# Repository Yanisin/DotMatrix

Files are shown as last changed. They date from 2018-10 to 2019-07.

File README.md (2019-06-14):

# DotMatrix

## What is this?

A STM32F070CB driving a LED DotMatrix.

## Prerequisities for building Firmware

  * You need an appropriate Cortex-M ARM toolchain. We suggest to use the
  ARM's [GNU Embedded Toolchain for Arm ](https://developer.arm.com/tools-and-software/open-source-software/developer-tools/gnu-toolchain/gnu-rm/downloads).
  Please note that the `gcc-arm-none-eabi` provided by Ubuntu 18.04 is currently broken and can't be used.

  * This project makes use of [libopencm3]()https://github.com/libopencm3/libopencm3) and [ChibiOS](http://www.chibios.org).
  In order to build `libopencm3` you need `Python 2`.

  * To download the firmware, you have two options:
     - Via USB: You need `dfu-util 0.9+` and a USB cable. Please not that `dfu-util 0.8` will not work.
     - Via SWD: You need `openocd` and a `ST-LINK v2 device`
  
  * Optional: `Docker`

You might be interested in some [libopencm3 examples here](https://github.com/libopencm3/libopencm3-examples).

The pull requests there might be an interesting source of information as well.

You will also want to have the manuals for your hardware at hand. These are the most important for software development:
 - Peripherals, memory layout, registers ... : [STM32F030x4/x6/x8/xC and STM32F070x6/xB MCUs](https://www.st.com/resource/en/reference_manual/dm00091010.pdf)
 - Pinouts, Electric Characteristcs, HW variants, clocks ...:
   [STM32F070CB Product Specification](https://www.st.com/resource/en/datasheet/stm32f070cb.pdf)
 - Exceptions (NVIC), instructions ... :
   [ARM® v7-M Architecture Reference Manual](https://static.docs.arm.com/ddi0403/eb/DDI0403E_B_armv7m_arm.pdf)

## Install & Build

Get the code:

    $ git clone https://github.com/libopencm3/libopencm3.git
    $ git clone https://github.com/ChibiOS/ChibiOS.git
    $ git clone https://github.com/Yanisin/DotMatrix.git

We provide a Dockerfile, containing the suggested toolchain, openocd, dfu-util and other tools as well.
You can build the container with:

    $ cd DotMatrix/
    DotMatrix$ docker build -t gcc-arm-none-eabi-8-2018-q4 .

Create a file named `settings.mk` in `DotMatrix/src` and provide an appropriate configuration.
You can use `DotMatrix/src/settings.mk.example` as input. This `settings.mk` works with the Docker container:

```
OPENCM3_DIR ?= /home/dev/app/src/libopencm3
CHIBIOS ?= /home/dev/app/src/ChibiOS
HW_VERSION = "HW_60x60_rev_0_5"
SUDO=
SIM=0
OOCD ?= openocd
OOCD_INTERFACE ?= stlink-v2-1
OOCD_TARGET ?= stm32f0x
```

You can start the container with:

    DotMatrix$ docker run -it --privileged --expose 4444 \
                  -v /dev/bus/usb:/dev/bus/usb \
                  -v `pwd`/../libopencm3:/home/dev/app/src/libopencm3 \
                  -v `pwd`/../ChibiOS:/home/dev/app/src/ChibiOS \
                  -v `pwd`:/home/dev/app \
                  gcc-arm-none-eabi-8-2018-q4:latest /bin/bash

You need to compile `libopencm3` before usage. This has to be done once.
With help of the toolchain container this is:

    dev@59e291eed30d:~/app$ cd src/libopencm3/
    dev@59e291eed30d:~/app/src/libopencm3$ make

ChibiOS is compiled on demand.

To compile the firmware / demo of your interest, just go to the directory and issue `$ make`. For instance:

    dev@59e291eed30d:~/app$ cd src/full/
    dev@59e291eed30d:~/app/src/full$ make

This should result in a binary `build/full.elf`.

### Content of the package

The software demos live in the src directory. There are are three main demos
avaiable:

- `src/stm32f070_miniblink` - a simple demo just blinking the LED
- `src/GameOfLife` - GameOfLife with all connected cells working together.
  Simple communication protocol over UART. The demo uses just libopencm3
  for HW interfacing.
- `src/full` - the 'catch all' demo. Includes GameOfLife and other applications
  that are selectable with an 'applet selector'. Provides a communication
  layer over I2C and UART. Automatically detects the topology of the boards
  at startup and chooses a 'master board'. Is based on an RTOS (ChibiOS).

There are also other small testing projects and a simulator that allows you to
run the 'full' demo on your host machine.

## Flashing

Flashing is done using the `make prg` and `make prg_usb` commands.
See `src/common.mk` for other makefile commands.

### SWD Interface

Attach the SWD interface of the MCU via stlink-v2 programmer and issue `$ make prg`

### USB DFU Bootloaders

There are two USB bootloaders.  One is burnt int the MCU from the manufacturer.
This one can be used in case of emergency to write "more specialized" bootloader stored 
in the FLASH, and that is used the flash the actual firmware.

The MCU itself has a bootloader burnt from the manufacture. This one requires
the Y1 oscillator popullated in order to work. It can be

#### Project Distributed Bootloader

There is a bootloader in `src/dfu`. Among other nice features this bootloader
allows to flash multiple interconnected boards at the same time.
Once compiled it can be flashed to ieach of the MCUs either using the stlink-v2
programer ( using `make prg` commad) or via the MCUs built in bootloader (using
the "make prg_bl" command).

If you want to use this bootloader (recommneded way), issue `$ make prg_usb` in
your project and connect the board over USB (or restart it, if it is already
connected. The flashing process will start as soon as the board reaches the
bootlader (you will see threee dots). If multiple boards are connected and
started at once, the firmware will be loaded to all of them.

The USB part of this bootloader seems to work even without Y1 resonator
populated, but the manufacturer does not say that it should be relyable.
If you have the the Y1 not populated keep this in mind.

#### MCU Manufacturers Bootloader

The MCU has a built in bootloader that is started if the BOOT0 pin is held hight
after reset is released. On the board there is reset circuitry with button.
If you hold this `reset` button for several seconds, you will get the board into
manufacturer provided bootloader. Among other ways (like USART, SPI, I2C) this
bootloader can program the flash via the USB DFU protocol. Use `make prg_bl` to
talk to this bootloader.  This can be used to flash the project bootloader or
have the wonderfull feeling of running bare-metal. If you want to run your
project without the project bootloader, You have to compile the demo with
`NO_BOOTLOADER=1`. 

Keep in mind that you can use this bootloader in USB DFU mode only if there is
the Y1 resonator present. If the Y1 is not present, you will need to use the
stlink-v2 or some other interface that this bootloader can handle even without
oscillator.  For details about this bootloader search for STs AN2606.

## Memory layout

Even though that you are programming C, it is important to know the memory
layout for debugging etc. The makefiles will take care of linking the code
at correct addreses.

ROM is mapped at 0x08000000 and the layout is as follows:

 Address | Size     | Usage
---------|----------|------------------------------------
0x0      | 0x4000   | Project Distributed Bootloader
0x4000   | 0x1C000  | Your application code (interrupt vectors, .text, .data)

RAM is mapped at 0x20000000 and the layout is as follows.

 Address | Size     | Usage
---------|----------|--------------------------------------------------------
0x0      | 0x100    | Interrupt vectors (loaded from ROM)
0x100    | 0x3F00   | Your application data (.data loaded from ROM, .bss)

For the location of IO registers for peripherals, consult the ST manual

# Hardware and mechanical parts
The currently used/latest HW is described in "pcb/60x60_dma". The board
is designed with KiCAD but there is the schematics exported in PDF 
and some assembly hints with list of needed parts are added as well.
The other folders in "src" are mostly unfinished various experiments/extension.

In the "mechanical" folder you can find the mechanical parts for 3D printing.
For each board PCB you will need one disp_support.stl.  The file is expected to
be printed with 0.4mm nozzle and 0.15mm layer height.  For connecting boards
you can use joint_cross_1_5m.stl for each corner (in older revision of the
board there is LED in the way so you need the use the one with the cuts for the
LED).

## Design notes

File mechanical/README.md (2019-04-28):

# Mechanical parts

The stl files are "fine tuned" for Creality Ender 3 with 0.4mm nozzle.
If some "tuning" is needed because of different printer they gen be recreated
using OpenSCAD.

## For Standalone Module

You need:
 
- 1x printed disp_support.stl
- 4x M3 nut
- 4x M3 15mm long spacer, one end male one end female (preferably nylon)

## For connecting modules
for each corner you will need joint_cross_1.5mm.stl.

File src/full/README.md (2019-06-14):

# DotMatrix full demo

This demo is a full-featured demo providing a common base for your hacking needs. It is based around
an RTOS (ChibiOS) and lets the user choose between multiple applications. It provides some
convinience utilities, such as physical topology detection and messaging protocol. If you do
not need these aminities, you may want to look at the simpler GameOfLife demo.

To see how you can create an applet, take a look at `applets/hello.c`. Do not forget to add
your applet to the Makefile. You do not have to register it explicitely, it will be done
by the `applet_add` macro. The applet's `run` function will be run when the applet is selected.
It is recommanded to contain a `while (!applet_should_end)` loop. You might want to set
your applet as `autostart` during debugging.

## ChibiOS basics

You can find documentation for ChibiOS at http://chibios.sourceforge.net/docs/19.1/full_rm/index.html.

## Functions suffixes

`I` suffix signifies function can be called from ISR locked state.
`S` suffix signifies function can be called from locked state.
`X` suffix signifies function can be called from any.

### Quick reference

- Getting current time: `chVTGetSystemTimeX`
- Sleep: `chThdSleep`
- Specifying time-outs: use `TIME_MS2I`, `TIME_S2I` or `TIME_INFINITE`
- Non-blocking calls: pass `TIME_IMMEDIATE` as a time-out paremeter
- Wait for multiple events: use `chEvtRegister` -- see `chooser_run` in `chooser_applet.c`
- Absolute time-outs: see `util/timeout.h`
- Panic: `chSysHalt`
- Memory allocation: `<chmemheaps.h>` `chHeapAlloc`
- Create a task: use `chThdCreateStatic` with working area allocatd by `THD_WORKING_AREA`

### Debugging

OpenOCD has support for ChibiOS threads. Use `info threads` and `thread X` to show and switch
threads respectivelly.

Also check `util/stack_usage.c` which you can use to get the biggest stack usage so far. Paste
these lines into GDB:
```
p stat_threads()
set print pretty on
p stat_thrinfo
```

## Messaging

There is a simple framing protocol which adds message IDs, checksum and routing information to
the messages. To send those messages, use either `i2c_send`, `i2c_broadcast` or `usart_send`.

To receive messages, the concept of message queues are used (`util/message_queue.h`). To get a
next message from the queue use `msg_rx_queue_get` and `msg_rx_queue_ack`. You will get a message
header and a "handle" to read the actual data from the queue buffer.

By default, the messages are automatically placed in the `default_queue` (both from i2c and uart).
If you want to change the queue, you can use the `dispatch_msg` callback of your applet.
This is used for example in the `GameOfLife`, where the time synchronization message (the tick)
is placed in a different queue than other messages.

## Hardware

Apart from UART and I2C (see previous paragraph), there are APIs for:
 - Buttons: `hw/buttons.h`
 - USB serial console: `console.h`
 - Unique Cell ID: `cell_id.h` (most of the time, you will want to use the short id from topology)
 - LED Matrix display: `hw/disp.h`

## Topology

When the full demo starts, it automatically enumerates all connected boards and elects a master
board. You can use this topology information to do proper display rotation (all boards can
show images rotated the same way), address the boards
over I2C or decide what will be shown on what board. Check the `util/topo.h` for more information.

## Other utilities

We have already touched on the topic of message queues. There is an alternative for streams without
any framing (`util/byte_queue.h`).

There are also utilities for basic operations with 2d integer vectors (used mostly for cell positions).

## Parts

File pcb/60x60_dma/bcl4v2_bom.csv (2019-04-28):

Reference | Quantity | Value | price [Kc] | price total | farnell | case | Datasheet
C1 C10 C3 | 3 | 4u7 | 2,6 | 7,8 | https://cz.farnell.com/taiyo-yuden/emk212b7475kg-t/cap-4-7-f-16v-10-x7r-0805/dp/2112841 | SMD 0805
C12 C13 | 2 | 220u | 16 | 32 | https://cz.farnell.com/avx/tajd107k010rnj/cap-100-f-10v-10-2917-reel/dp/2217319 | EIA-7343-20
C14 C15 | 2 | 2pF | 0,67 | 1,34 | https://cz.farnell.com/multicomp/mc0603n2r0c500ct/cap-2pf-50v-c0g-np0-0603/dp/1759043RL | SMD 0805
C11 C2 C4 | 3 | 100n | 0,6 | 1,8 | https://cz.farnell.com/multicomp/mcu0805r104kct/cap-0-1-f-50v-10-x7r-0805/dp/9406387 | SMD 0805
C6 C7 C8 C9 | 4 | 100n | 0,6 | 2,4 | https://cz.farnell.com/multicomp/mc0603b104m250ct/cap-0-1-f-25v-20-x7r-0603/dp/2627428 | SMD 0805
D1 D2 | 2 | Shottky | 1,48 | 2,96 | https://cz.farnell.com/taiwan-semiconductor/b0520lw-rhg/diode-rectif-20v-0-5a-sod123/dp/1863141 | SOD-123
D5 | 1 | LED | 0,3 | 0,3 | ebay | SMD 0805
D6 | 1 | LED_MATRIX_8x8 | 70 | 70 | https://www.ges.cz/cz/spl-32-GES06600358.html | LED_MATRIX_8x8_60.2mmx60.2mm
J1 J2 J4 J5 J6 J7 J8 J9 | 8 | Conn_01x05 | 0,7375 | 5,9 | https://www.ges.cz/cz/pls-40s-GES06600276.html | Pin_Hdr_1x05_2.54mm
 |  |  |  | 0
J14 | 1 | Conn_01x02 | 0,3 | 0,3 | https://www.ges.cz/cz/pls-40r1-GES06614710.html | Pin_Hdr_1x02_2.54mm_angled_handsolder
J15 | 1 | Conn_01x04 | 0,6 | 0,6 | https://www.ges.cz/cz/pls-40r1-GES06614710.html | Pin_Hdr_1x04_2.54mm_angled_handsolder
J3 | 1 | USB_OTG | 6 | 6 | https://cz.farnell.com/multicomp/mc001009/micro-usb-type-b-receptacle-smt/dp/2506104?st=micro%20usb | USB_Micro-B
Q1 | 1 | BSS138 | 1,71 | 1,71 | https://cz.farnell.com/nexperia/bss138p-215/mosfet-n-ch-60v-0-36a-sot23/dp/1859849?st=bss138 | SOT-23
Q2 | 1 | IRLML6402 | 3,7 | 3,7 | https://cz.farnell.com/infineon/irlml6402trpbf/mosfet-p-ch-20v-3-7a-sot-23/dp/9103503?st=IRLML6402 | SOT-23
R14 R2 | 2 | 220k |  | 0 |  | SMD 0805
R15 R17 | 2 | R |  | 0 |  | SMD 0805
R16 | 1 | 820k |  | 0 |  | SMD 0805
R3 | 1 | 470 |  | 0 |  | SMD 0805
R1 R13 R4 | 3 | 10k |  | 0 |  | SMD 0805
R5 | 1 | 1k |  | 0 |  | SMD 0805
SW1 SW2 SW3 | 3 | SW_Push | 1,6666666667 | 5,0000000001 | lcsc | switch_K2-1112SA-A4SW-01
 |  |  |  | 0
U1 | 1 | MIC2091-1YM5-TR | 3,4 | 3,4 | https://cz.farnell.com/microchip/mic2091-1ym5-tr/power-switch-100ma-sot23-5/dp/2509914RL?st=mic2091 | SOT-23
U2 | 1 | STM32F070CBTx | 40 | 40 | provided by badger | LQFP-48_7x7mm_Pitch0.5mm
U3 | 1 | 74HC595 | 3,7 | 3,7 | https://cz.farnell.com/on-semiconductor/mc74hc595adtr2g/ic-sm-logic-74hc-register/dp/1607848?st=74HC595 | SO-16-N | http://www.ti.com/lit/ds/symlink/sn74hc595.pdf
U4 | 1 | TBD62783A(replaced by TD62783AFG) | 12 | 12 | https://www.ebay.com/itm/10pcs-NEW-TD62783AFG-SOP-18-TOSHIBA/282239141886 | SOIC-18W_7.5x11.6mm_Pitch1.27mm | http://toshiba.semicon-storage.com/info/docget.jsp?did=30523&prodName=TBD62783APG
U5 | 1 | TLC5916 | 24 | 24 | https://cz.farnell.com/texas-instruments/tlc5916id/ic-led-driver-linear-16-soic/dp/1755247?st=TLC5916 | SO-16-N
Y1 | 1 | Resonator | 10 | 10 |  | CSTCE_G
Y2 | 1 | ABS07-120-32.768kHz-T | 10 | 10 |  | crystal_ABS07-120-xx | ~
other:
 | 4 | nylon spacers
 | 4 | nylon nuts
 | 4 | mini breadboard joints

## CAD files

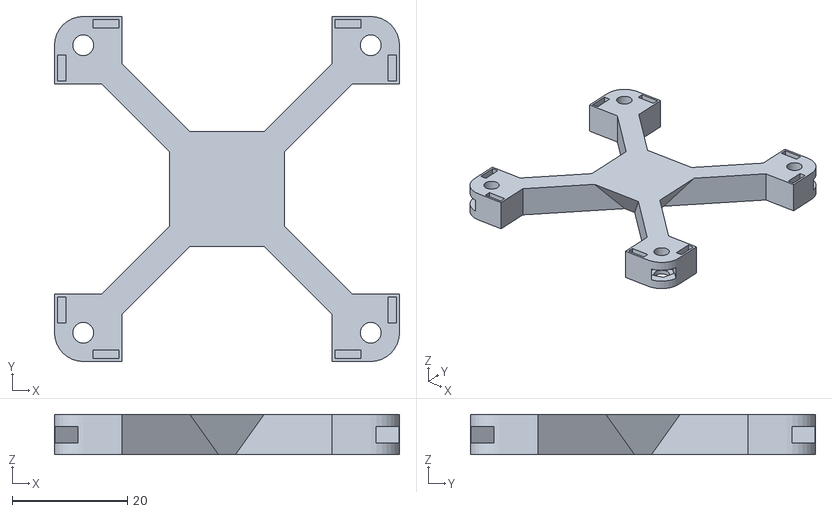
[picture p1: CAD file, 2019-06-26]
mechanical/disp_support_w_magnet.stl
60.0 x 60.0 x 7.00

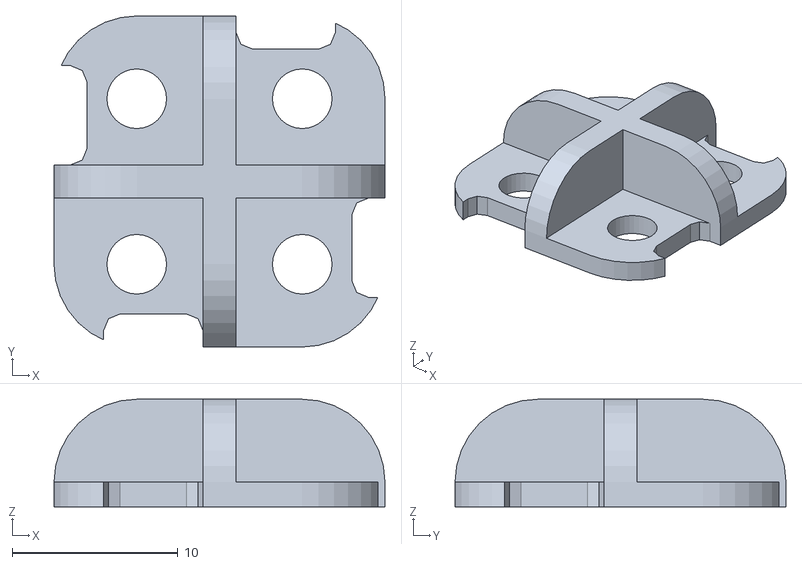
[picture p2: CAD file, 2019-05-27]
mechanical/joint_cross_1_5m_cut_for_v05.stl
20.0 x 20.0 x 6.50

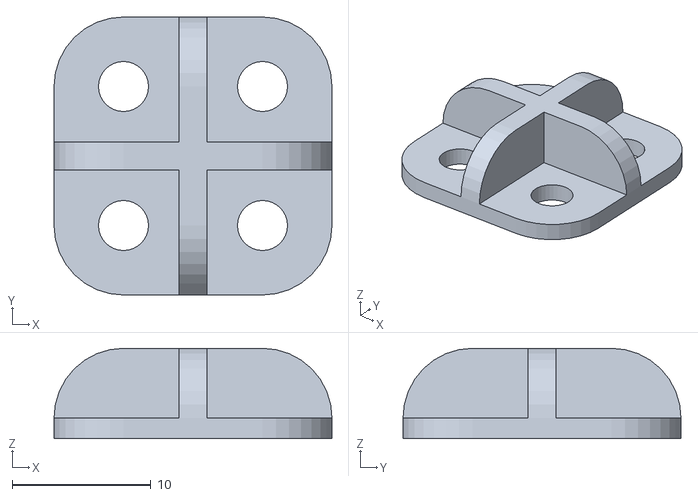
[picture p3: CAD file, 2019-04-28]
mechanical/joint_cross_1_5m.stl
20.0 x 20.0 x 6.50

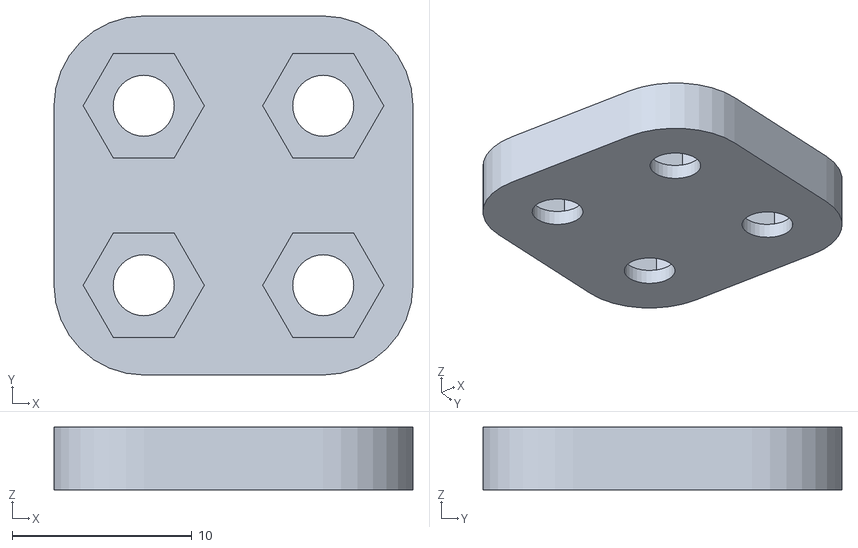
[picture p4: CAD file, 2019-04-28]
mechanical/joint_2x2_10mm.stl
20.0 x 20.0 x 3.50

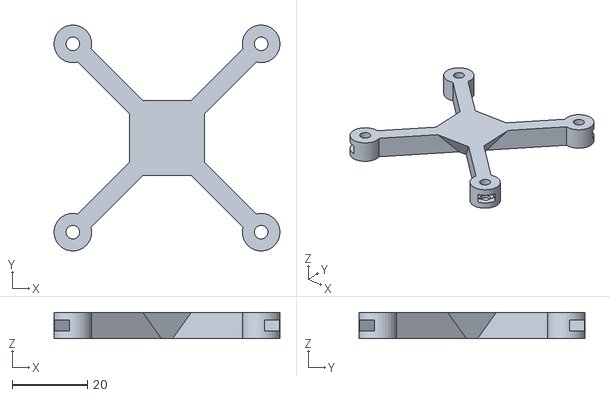
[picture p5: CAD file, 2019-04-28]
mechanical/disp_support.stl
60.0 x 60.0 x 7.00

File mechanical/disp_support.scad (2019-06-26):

hole_dia = 3.6;
corner_dia = 10;
corner_height = 7;
nut_height = 2.9;
nut_dia=0.8 + (5.5+6)/2;
nut_dia_clearance=0.4;
nut_offset = 1;
nut_recess = 1;
center_side=20;
center_height=7;
conn_width=2.54;
conn_length=2.54 * 14;
	corner_clearance=0.5;

//corner();

//body();
support();
$fn=32;
/* connector */
//color("red")
//translate([30 - conn_width,-conn_length/2,0])
//cube ([conn_width,conn_length, corner_height]);
 
module corner()
{
	
	union(){
	cylinder(h=corner_height,d=corner_dia);
	translate([0,-corner_dia/2,0])
	cube([25-conn_length/2-corner_clearance,corner_dia,corner_height]);
	rotate([0,0,-90])
	translate([0,-corner_dia/2,0])
	cube([25-conn_length/2-corner_clearance,corner_dia,corner_height]);
	}

}

module support()
{
difference(){
	body();
	holes();
	nut_holes();
	magnet_holes();
}
}

module hole(){
	cylinder(h=corner_height,d=hole_dia);
}

module nut_hole(){
	cube_width= nut_dia * sqrt(3)/2; 
	translate([0,0,nut_offset])
	cylinder(h=nut_height,d=nut_dia, $fn=6);
	translate([0,0,nut_offset+nut_recess]){
	cylinder(h=nut_height,d=nut_dia, $fn=6);
	translate([0,-cube_width/2,0])
	cube([20,cube_width,nut_height]);
}

}

module magnet_holes()
{
	magnet_x=1.5;
	magnet_y=4.5;
	magnet_z=6;
	x_offset=30 - magnet_x-0.5;
	/*0.5 is wall size around magnet*/
	y_offset = conn_length/2 + corner_clearance+0.5;
	z_offset = corner_height - magnet_z;

	translate([x_offset,y_offset,z_offset])
		cube([1.5,4.5,magnet_z]);
	translate([x_offset,-y_offset-magnet_y,z_offset])
		cube([1.5,4.5,magnet_z]);
	translate([-x_offset-magnet_x,y_offset,z_offset])
		cube([1.5,4.5,magnet_z]);
	translate([-x_offset-magnet_x,-y_offset-magnet_y,z_offset])
		cube([1.5,4.5,magnet_z]);
rotate([0,0,90]){
	translate([x_offset,y_offset,z_offset])
		cube([1.5,4.5,magnet_z]);
	translate([x_offset,-y_offset-magnet_y,z_offset])
		cube([1.5,4.5,magnet_z]);
	translate([-x_offset-magnet_x,y_offset,z_offset])
		cube([1.5,4.5,magnet_z]);
	translate([-x_offset-magnet_x,-y_offset-magnet_y,z_offset])
		cube([1.5,4.5,magnet_z]);}
}

module holes()
{
translate([25,25,0])
hole();
translate([25,-25,0])
hole();
translate([-25,25,0])
hole();
translate([-25,-25,0])
hole();
}

module nut_holes()
{
translate([25,25,0])
	rotate([0,0,45])
nut_hole();
translate([25,-25,0])
	rotate([0,0,-45])
nut_hole();
translate([-25,25,0])
	rotate([0,0,135])
nut_hole();
translate([-25,-25,0])
	rotate([0,0,-135])
nut_hole();
}


module body()
{
//translate([-center_side/2,-center_side/2,0])
//cube([center_side,center_side,center_height]);

translate([0,0,center_height/2])
linear_extrude(height = center_height, center = true, convexity = 10, slices =
20, scale = 2, $fn = 16) {
square([center_side*0.5,center_side *0.5],center=true);
}

rotate([0,0,45])
translate([-sqrt(2)*25,-2.5,0])
cube([2*sqrt(2)*25,5,corner_height]);
rotate([0,0,-45])
translate([-sqrt(2)*25,-2.5,0])
cube([2*sqrt(2)*25,5,corner_height]);
translate([25,25,0])
rotate([0,0,-90])
corner();
translate([25,-25,0])
rotate([0,0,180])
corner();
translate([-25,25,0])
rotate([0,0,0])
corner();
translate([-25,-25,0])
rotate([0,0,90])
corner();
}

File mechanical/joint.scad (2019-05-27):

use <metric_iso_screw.scad>


thickness = 1.5;
hole_dia = 3.6;
spacing = 10;
width = 10;
cross_thickness=2;
cross_height = 10;

rows=2;
//rows=2;

multiple_x = 4;
multiple_y = 4;
multiple_spacing=3;

nut_height=2.5;
nut_dia = 1 + (5.5+6)/2;


module body()
{
$fn=32;
	union(){
		translate([0,0,0])cylinder(h=thickness,d=width);
		translate([spacing,0,0])cylinder(h=thickness,d=width);
		translate([0,spacing*(rows-1),0])cylinder(h=thickness,d=width);
		translate([spacing,spacing*(rows-1),0])cylinder(h=thickness,d=width);
		translate([0,-width/2,0])cube([spacing,width+spacing*(rows-1),thickness]);
		translate([-width/2,0,0])cube([spacing+width,spacing*(rows-1),thickness]);
		/* cross */
		translate([0,spacing/2 - cross_thickness/2,thickness]) difference(){
			union(){
				rotate([-90,0,0])translate([0,0,0])cylinder(h=cross_thickness,d=width);
				rotate([-90,0,0])translate([spacing,0,0])cylinder(h=cross_thickness,d=width);
				translate([0,0,-spacing/2])cube([spacing,cross_thickness,spacing]);
			}
			translate([-spacing/2,0,-spacing])cube([spacing*2,spacing*(rows-1),spacing]);
		}

		translate([spacing/2 + cross_thickness/2,0,thickness]) rotate([0,0,90]) difference(){
			union(){
				rotate([-90,0,0])translate([0,0,0])cylinder(h=cross_thickness,d=width);
				rotate([-90,0,0])translate([spacing,0,0])cylinder(h=cross_thickness,d=width);
				translate([0,0,-spacing/2])cube([spacing,cross_thickness,spacing]);
				}
			translate([-spacing/2,0,-spacing])cube([spacing*2,spacing*(rows-1),spacing]);
		}

	}
}

module holes()
{
$fn=32;
	for (i = [0:(rows-1)]) {
		translate([0, i * spacing,0])cylinder(h=thickness,d=hole_dia);
		translate([spacing,i *spacing,0])cylinder(h=thickness,d=hole_dia);
	}
}


module holes_thread()
{
$fn=32;
	for (i = [0:(rows-1)]) {
		translate([0, i * spacing,0])
screw_thread_iso_inner(
        d=3,
        lt=6,
        $fn=60
    );



		translate([spacing,i *spacing,0])
screw_thread_iso_inner(
        d=3,
        lt=6,
        $fn=60
    );


	}
}


module nuts()
{
$fn=6;
	for (i = [0:(rows-1)]) {
		translate([0, i * spacing,0])cylinder(h=nut_height,d=nut_dia,$fn=6);
		translate([spacing,i *spacing,0])cylinder(h=nut_height,d=nut_dia,$fn=6);
	}
}

module joint() 
{
	difference () {
		body();
		holes();
		translate([0,0,thickness-nut_height])nuts();

	}
}


module joint_thread() 
{
	difference () {
		body();
		
		holes_thread();
//		translate([0,0,thickness-nut_height])nuts();

	}

}

module multiple()
{
		size_x = width + spacing;
		size_y = width + spacing * (rows -1);
	for (x = [1:multiple_x]) {
		for (y = [1:multiple_y]) {
		translate([(x-1)*(size_x+multiple_spacing),(y-1)*(size_y+multiple_spacing),0])joint();
		}
	}
}

module joint_simple()
{
	difference () {
		body();
		
		holes();
//		translate([0,0,thickness-nut_height])nuts();

	}

}

module joint_cut_v05()
{
difference(){
translate([-5,-5,0])
joint_simple();

translate([-6,-14,0])
minkowski(){
cylinder(r=1,h=2,$fn=8);
cube([4,5,5]);
}

rotate([0,0,90])
translate([-6,-14,0])
minkowski(){
cylinder(r=1,h=2,$fn=8);
cube([4,5,5]);
}


rotate([0,0,180])
translate([-6,-14,0])
minkowski(){
cylinder(r=1,h=2,$fn=8);
cube([4,5,5]);
}


rotate([0,0,270])
translate([-6,-14,0])
minkowski(){
cylinder(r=1,h=2,$fn=8);
cube([4,5,5]);
}

}
}

//multiple();
//joint_thread();
//joint_simple();

joint_cut_v05();

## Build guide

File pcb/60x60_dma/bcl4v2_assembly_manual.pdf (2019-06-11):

## Dot Matrix Assembly Manual

For hardware revision 0.6
Power Supply
Populate C1, C3, U1 and Q2. Verify that 5V test point is not shorted to GND neither to 3V3 test points. If not, you can apply 5V voltage on the GND and VCC pins of the J9 connector (see the other side of the PCB) and verify voltage on 5V and 3V3 test points.
Reset and Boot Selection
At least C11, R13 and R16 needs to be soldered to reliable boot the MCU. Bootloader can be then started by shorting the J14, applying power and disconnecting the short. If SW3, C10 and Q1 is populated, then SW3 can be used either to reset MCU (short press) or entering bootloader (long press). For now do not solder the SW3 yet as it will be in the way while soldering other parts.
Debug LED
Populate R5 and D5, while there solder R3 too. Keep in mind LED polarity (the green dots on the LED should align with the marked pin). Take care to not touch the LED resin blob with the soldering iron or not overheat the diode.
If the MCU (U2) is not soldered you can test LED by connecting TP6 to GND with power applied. If the MCU is already soldered, and the power is applied it should flash the LED several times.

## MCU and USB connector

You should be now skilled enough to solder the USB connector. Use 5V, GND, D+ and D- testpoints to check for shorts Then connect USB cable and check conductivity. If not presoldered now you can solder the MCU (U2) and the 0603 size capacitors C6, C7, C8, C9. If the preprogrammed MCU was used the LED should blink if you connect the power via the USB.

## External Clock

There are two types of external clock the High Speed one, used e.g. for USB and the Low Speed Clock that is used for RTC. For HSE (High Speed Clock) Y1 is needed. LSE (Low Speed Clock), Y2, C14, C15 are needed. LSE is not needed for this workshop, but it's easier to solder now, than on the complete kit.

## Led Matrix Driving

Solder U3,U4,U5 (R3 should be already in place). Use the LED matrix as the holder for soldering the "socket headers". Don't forget that the LED matrix should be on the other side of the PCB than the rest of the components. Once assembled correctly and powered the preloaded MCU should show some demo on the matrix.

## Buttons

This is optional. It makes the board more versatile and the demo can't be controlled without them. It's easier to do before the side headers are soldered but it still can be done later if you are getting short on time now. Solder SW1 and SW2 and R2, R14, C2, C4. (It's good time for SW3 now too.) The resistors and capacitors form the hardware button debounce. If you for some reason need a quick response on cost of doing the button debounce in software they can be omitted (the buttons can't be used in the demo in that case).

## Interface headers

The headers J1, J2, J4, J5, J6, J7, J8, J9 needs to be soldered now. The headers need to be as perpendicular to the PCB. If possible use a jig, or pile of another PCBs to hold the headers in place.

## Mechanical part

Now you should have the electrical part complete and you only need to complete the mechanical part. Insert the M3 nuts in the holes of the display support. You might eventually need do clean the 3D part a bit. The larger central part of the support should face upwards to the Display. If mounted remove the Display, and use the four nylon spacers to secure the display support on the PCB. Pay attention to properly aligned nuts in order to not damage the threading on the spacers. Reinstall the LED Display. The small 3D printed squares and small solder-less breadboards are for interconnecting the boards. The holes in the breadboard are connected in lines as the protrusion on top shows. If connected in wrong direction it will short circuit the header. The nuts with washers are for mounting the board to some support.

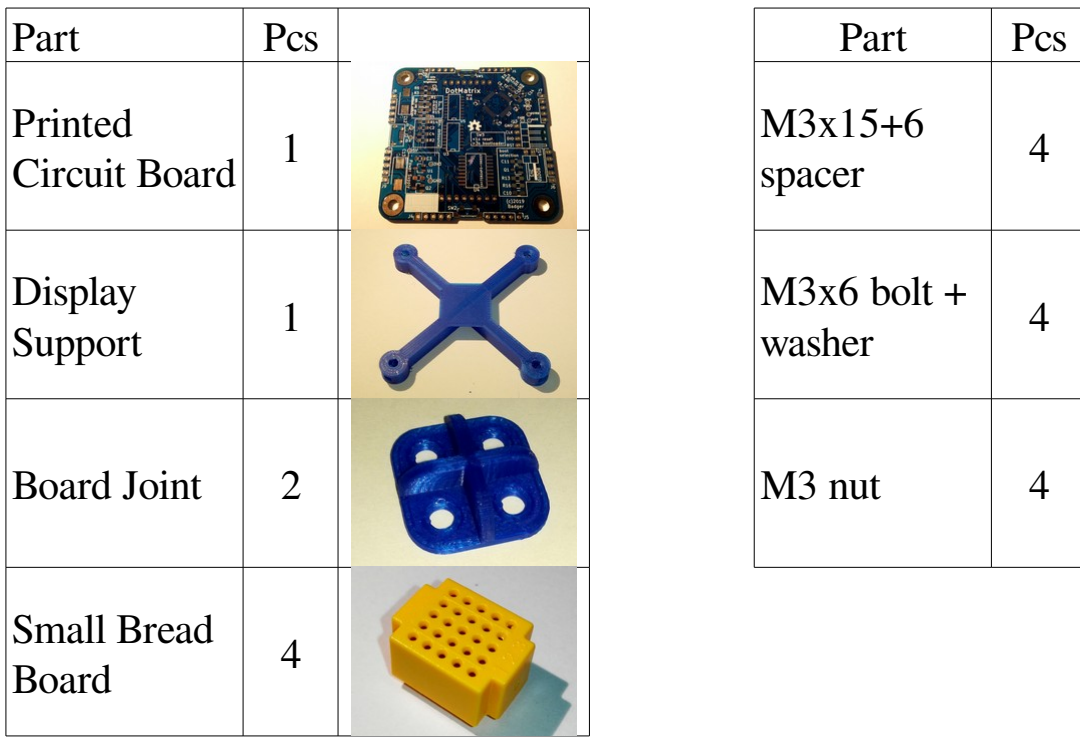
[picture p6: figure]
Part; Pcs; Printed; Circuit Board; M3x15+6 spacer; Display; Support; M3x6 bolt +; washer; Board Joint; M3 nut; Small Bread; Board

Table 1: Mechanical components

Reference | Pcs | Value | case
C1, C10, C3 | 3 | 4u7 | SMD 0805

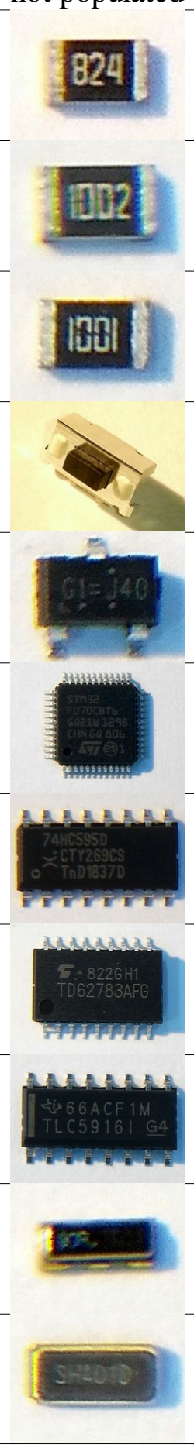
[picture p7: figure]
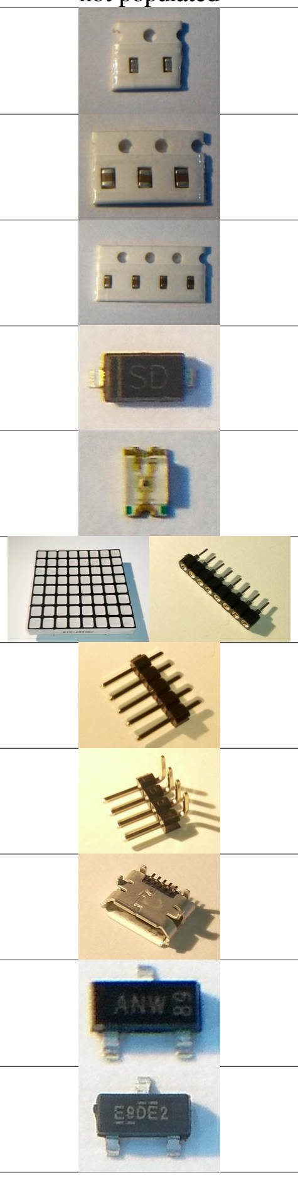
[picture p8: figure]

C12, C13 | 2 | 220u | EIA-7343-20 | not populated
C14, C15 | 2 | 2pF | SMD 0805
C11, C2, C4 | 3 | 100n | SMD 0805
C6, C7, C8, C9 | 4 | 100n | SMD 0805
D1, D2 | 2 | Shottky | SOD-123
D5 | 1 | LED | SMD 0805
D6 | 1 | | LED_8x8_60x6 0
J1, J2, J4, J5, J6, J7, J8, J9 | 8 | | Hdr_1x05_2.54
J15 | 1 | | hdr_1x04_2.54 angled
J3 | 1 | | USB_Micro-B
Q1 | 1 | BSS138 | SOT-23
Q2 | 1 | IRLML6402 | SOT-23
R14, R2 | 2 220k | SMD 0805
R15, R17 | 2 | R | SMD 0805 not populated
R16 | 1 | 820k | SMD 0805
R1, R13, R4 | 3 | 10k | SMD 0805
R3, R5 | 2 | 1k | SMD 0805
SW1, SW2, SW3 | 3 | | switch K2-1112SA
U1 | 1 | RT9166-33GVL | SOT-23
U2 | 1 | STM32F070C BTx | LQFP-48
U3 | 1 | 74HC595 | SO-16-N
U4 | 1 | TD62783AFG SOIC-18W
U5 | 1 | TLC5916 | SO-16-N
Y1 | 1 | Resonator | CSTCE_G
Y2 | 1 | ABS07-120-32.768kHz-T | ABS07-120-xx

Table 2: Components list

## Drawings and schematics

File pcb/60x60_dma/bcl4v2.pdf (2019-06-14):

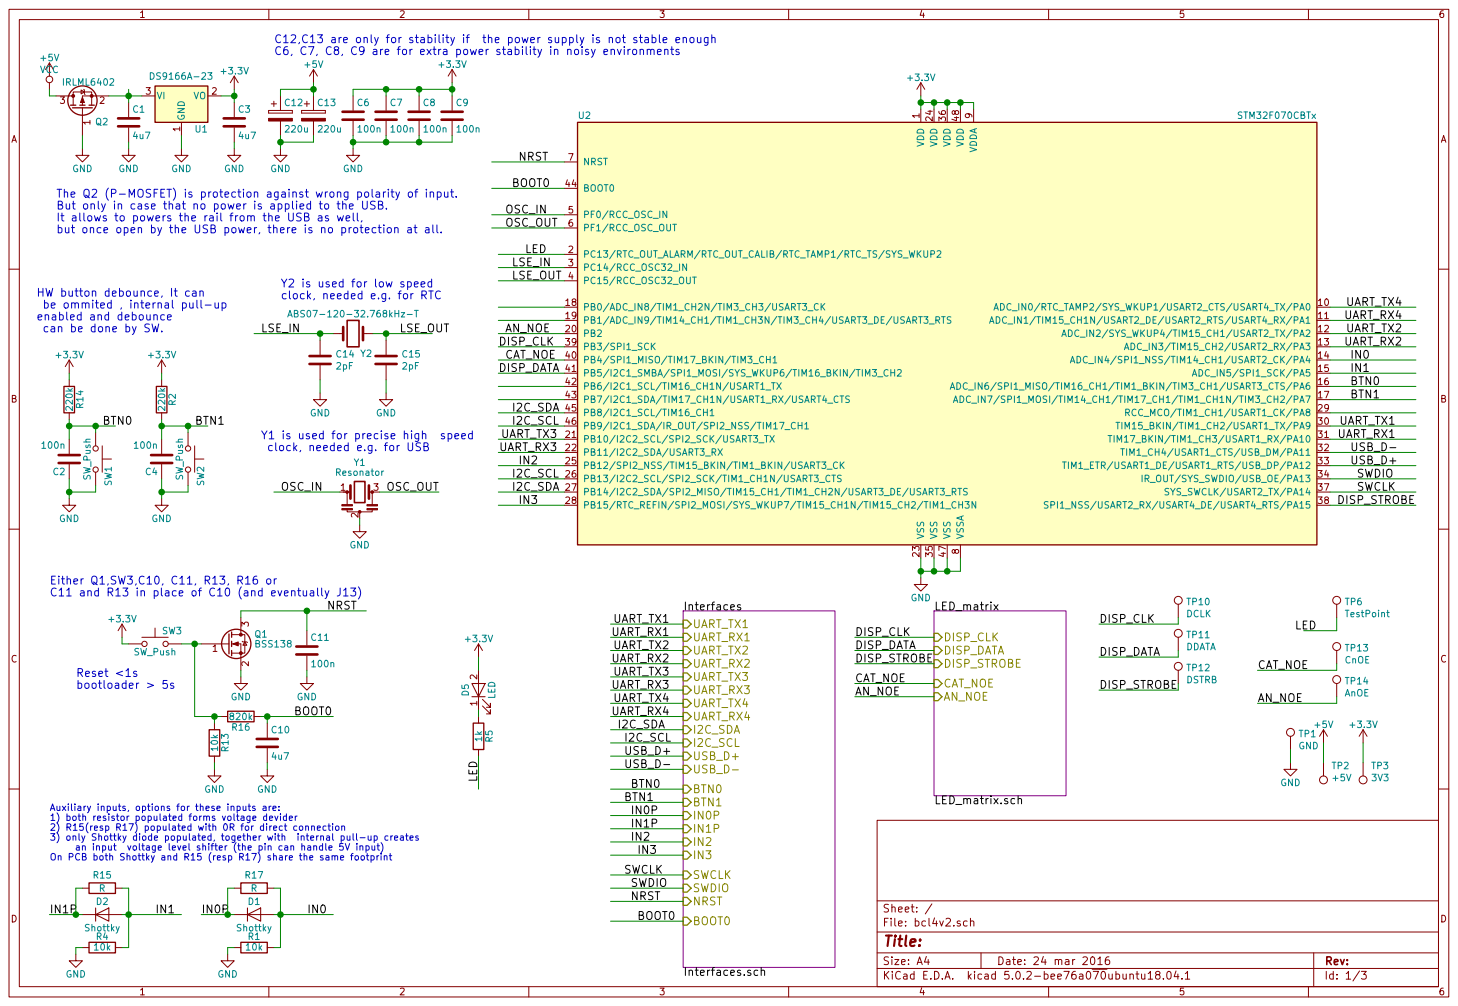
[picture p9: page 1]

can be done by SW. VCC
IRLML6402 GND The Q2 (P-MOSFET) is protection against wrong polarity of input.

C6, C7, C8, C9 are for extra power stability in noisy environments

But only in case that no power is applied to the USB.
It allows to powers the rail from the USB as well,
but once open by the USB power, there is no protection at all.

TP6 TestPoint Y2 is used for low speed
clock, needed e.g. for RTC
Y2 ABS07-120-32.768kHz-T C14

HW button debounce, It can
be ommited , internal pull-up
enabled and debounce

Y1 is used for precise high speed
clock, needed e.g. for USB

BOOT0 Reset <1s bootloader > 5s Either Q1,SW3,C10, C11, R13, R16 or
C11 and R13 in place of C10 (and eventually J13)

10k Auxiliary inputs, options for these inputs are:
1) both resistor populated forms voltage devider
2) R15(resp R17) populated with 0R for direct connection
3) only Shottky diode populated, together with internal pull-up creates
an input voltage level shifter (the pin can handle 5V input)
On PCB both Shottky and R15 (resp R17) share the same footprint

Id: 1/3 Title: File: bcl4v2.sch Sheet: /

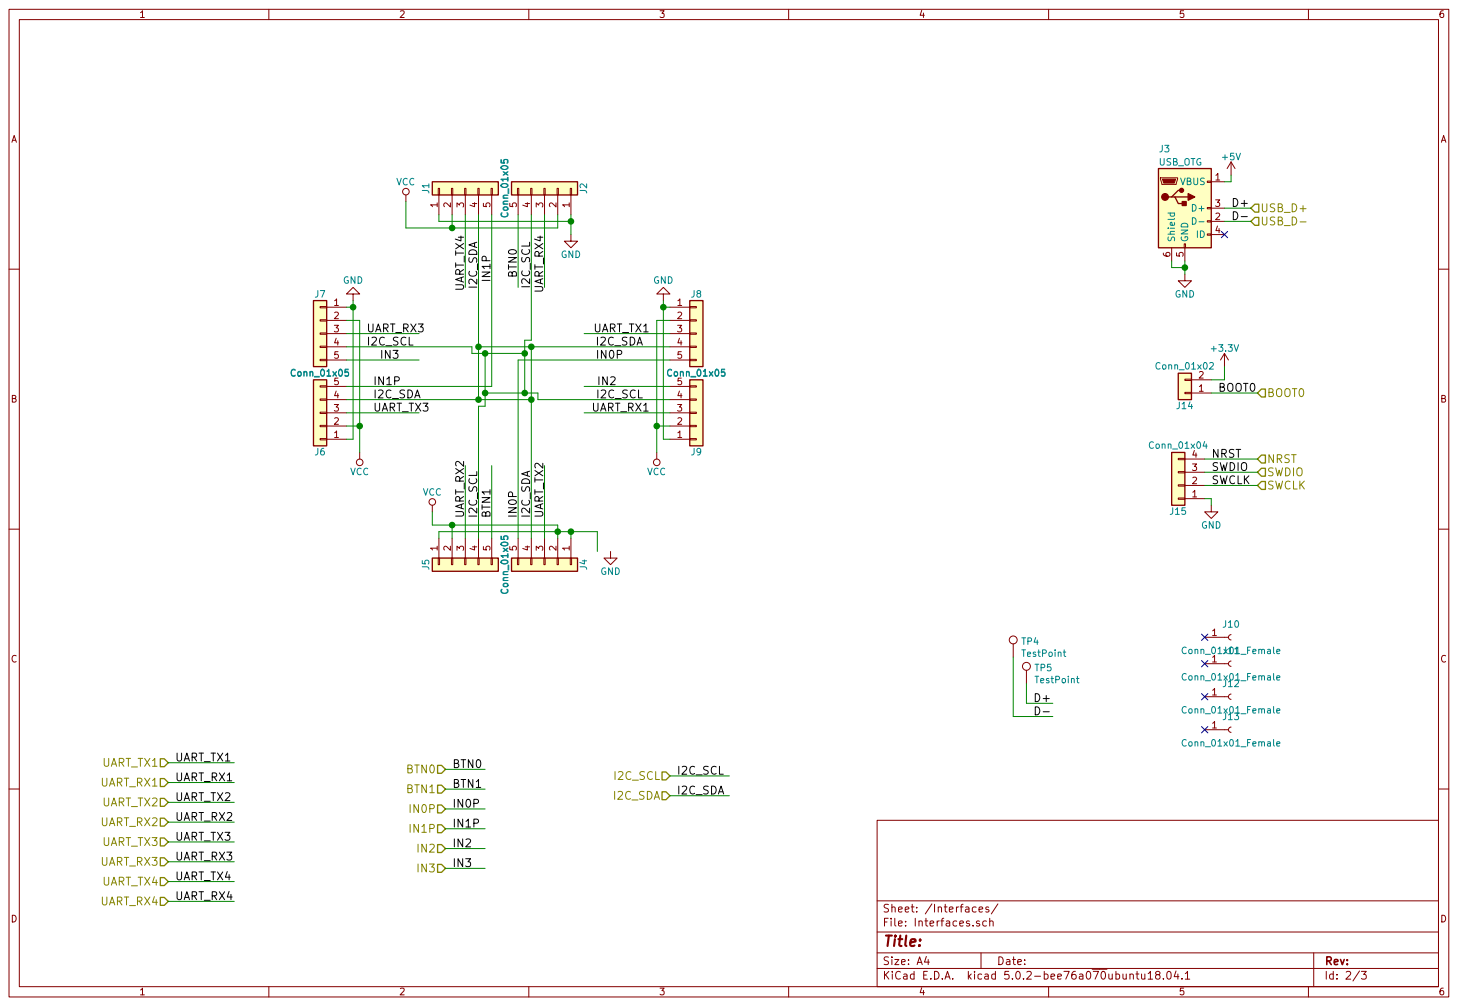
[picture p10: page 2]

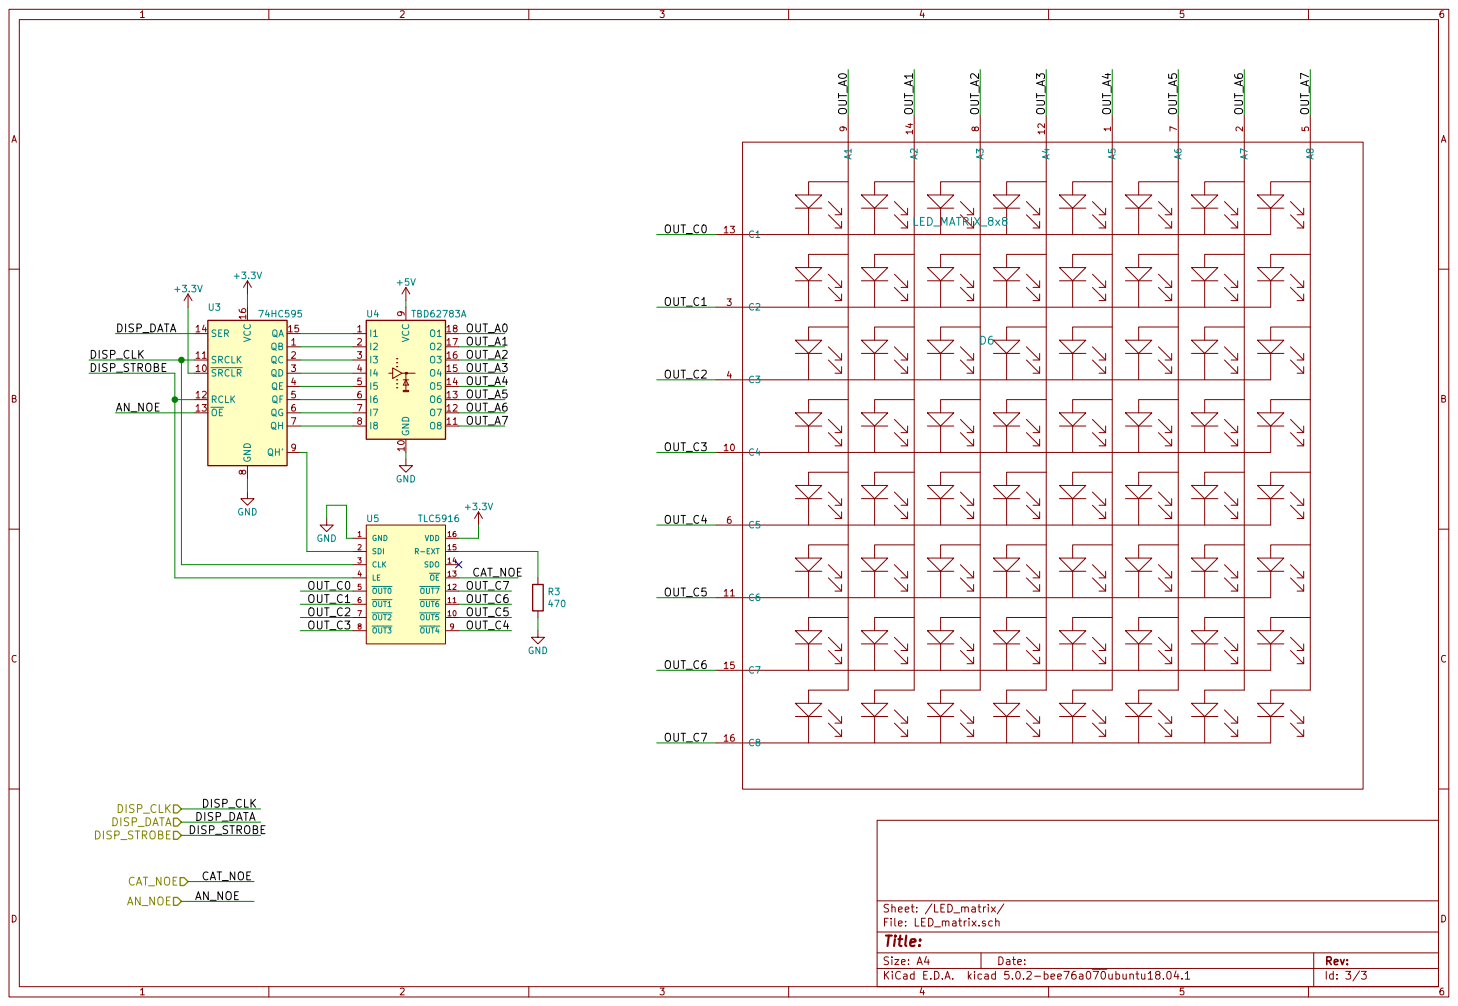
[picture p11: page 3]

8 QH' 9 U3 74HC595 GND 1 OUT5 10 OUT6 11 OUT7 12 OE 13 SDO 14 R-EXT 15 VDD 16 SDI 2 CLK 3

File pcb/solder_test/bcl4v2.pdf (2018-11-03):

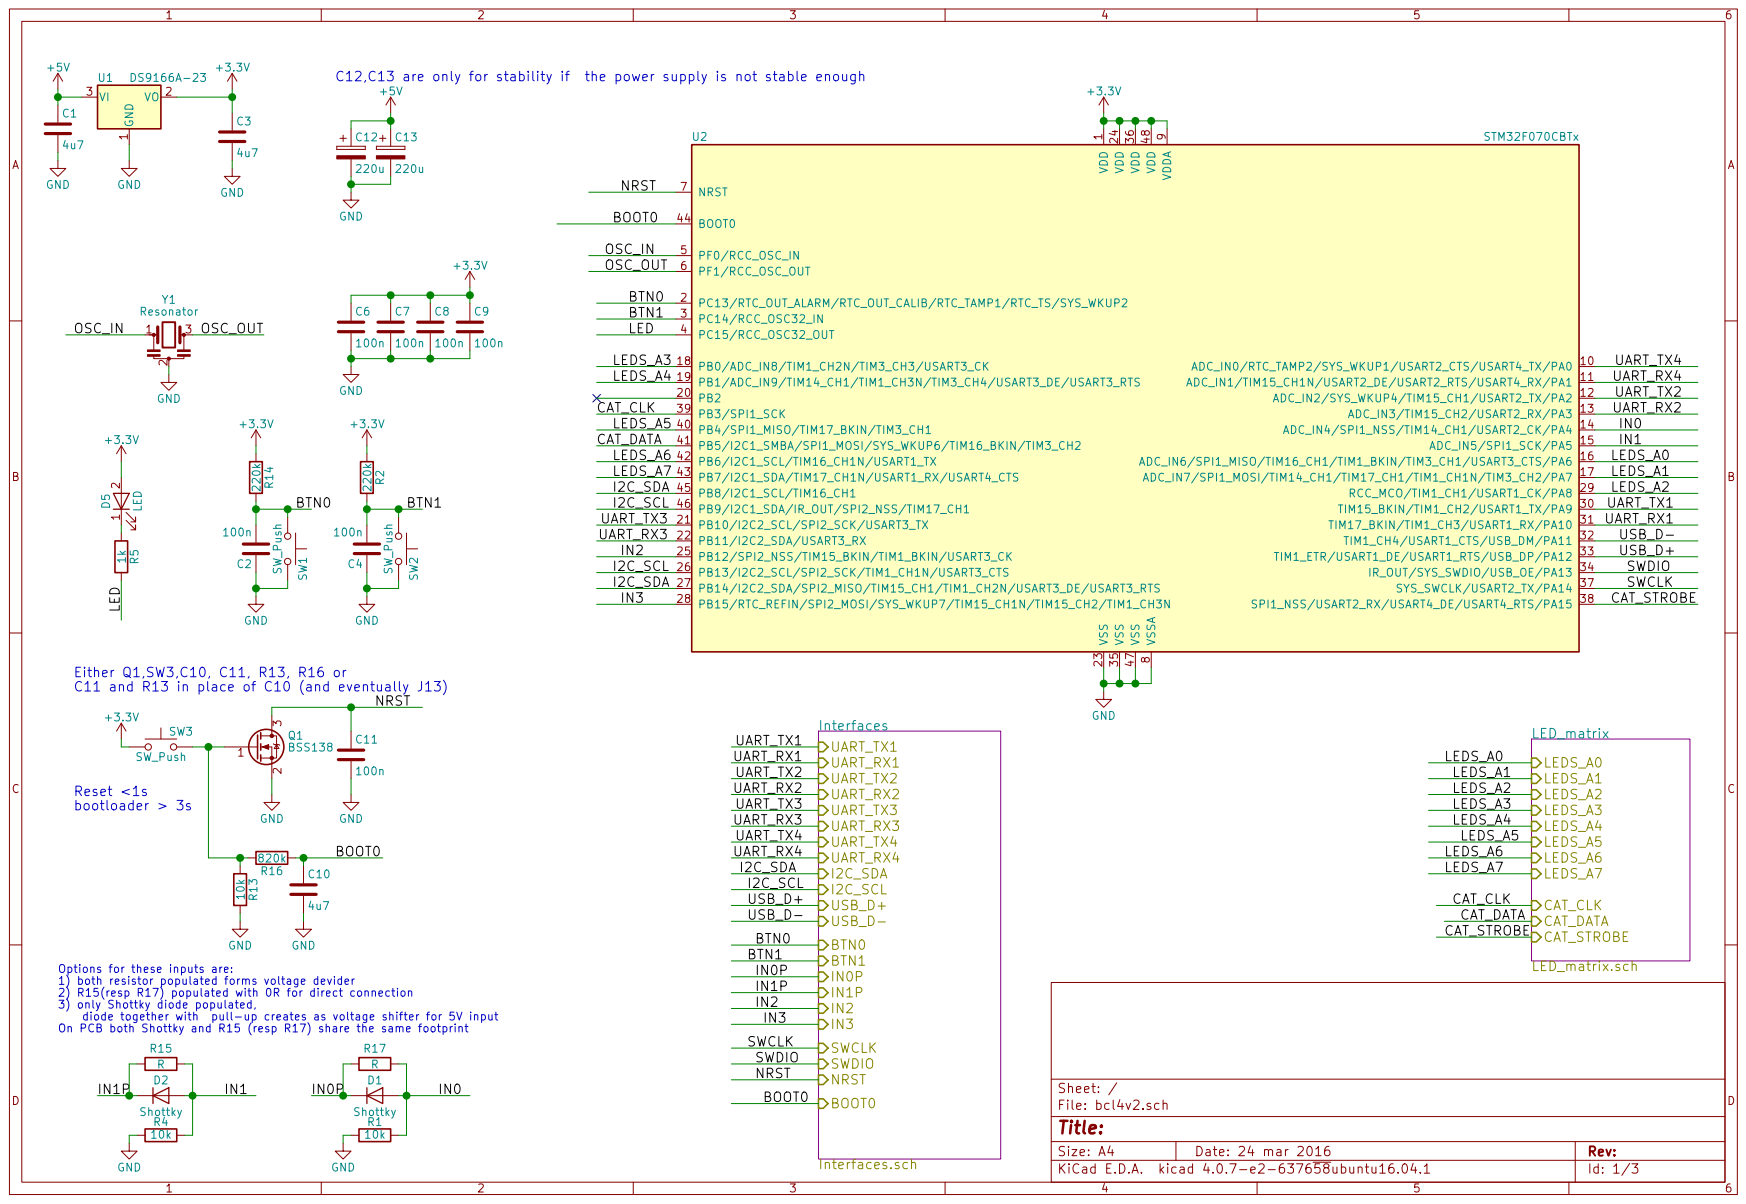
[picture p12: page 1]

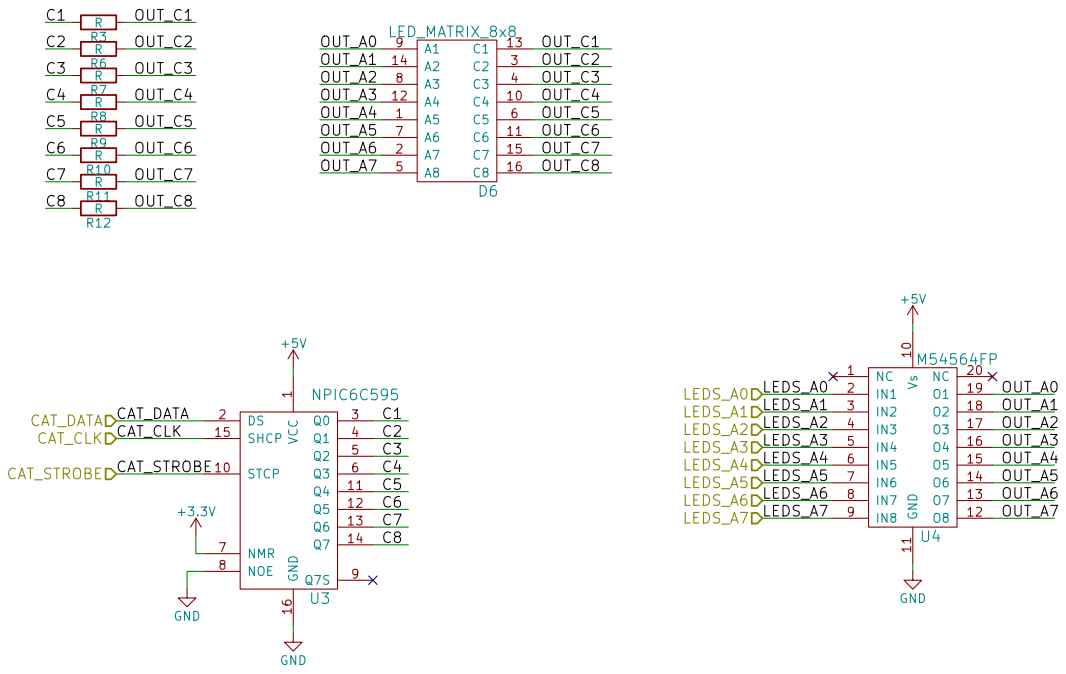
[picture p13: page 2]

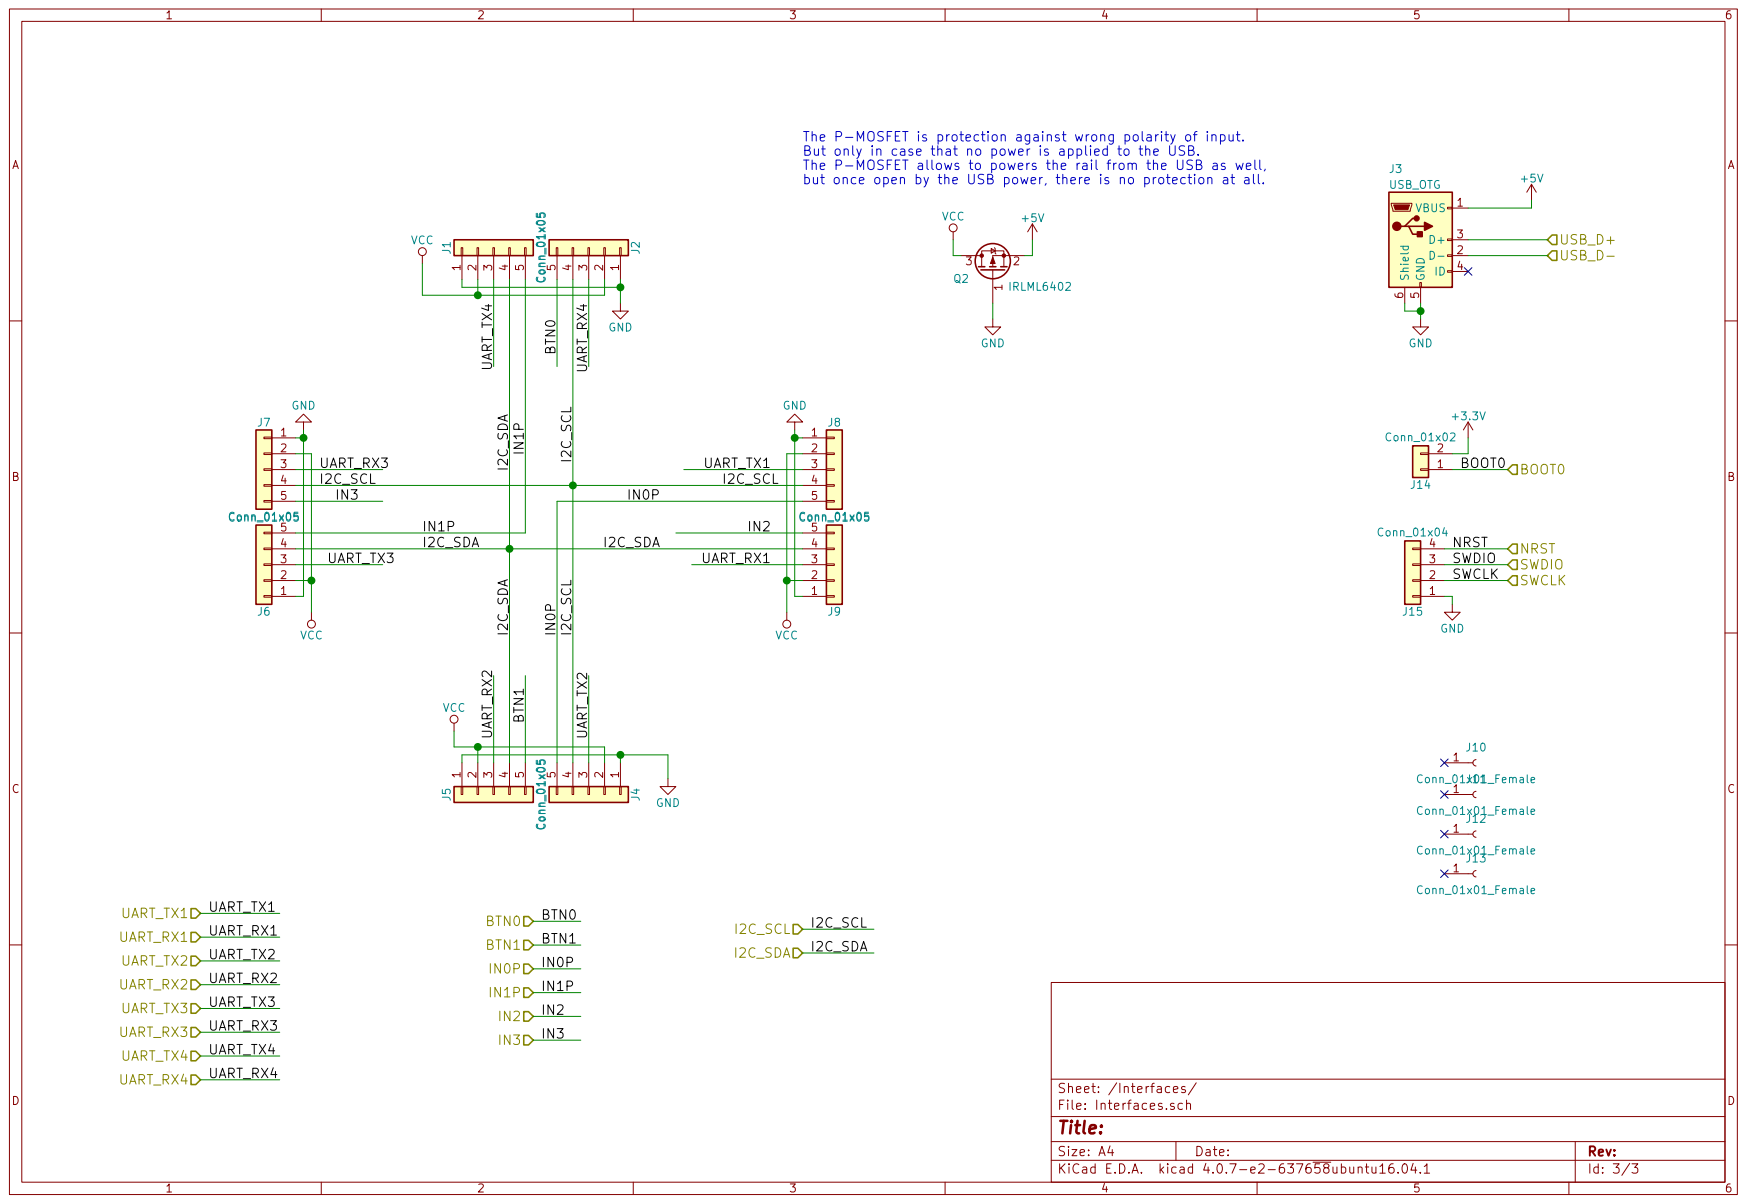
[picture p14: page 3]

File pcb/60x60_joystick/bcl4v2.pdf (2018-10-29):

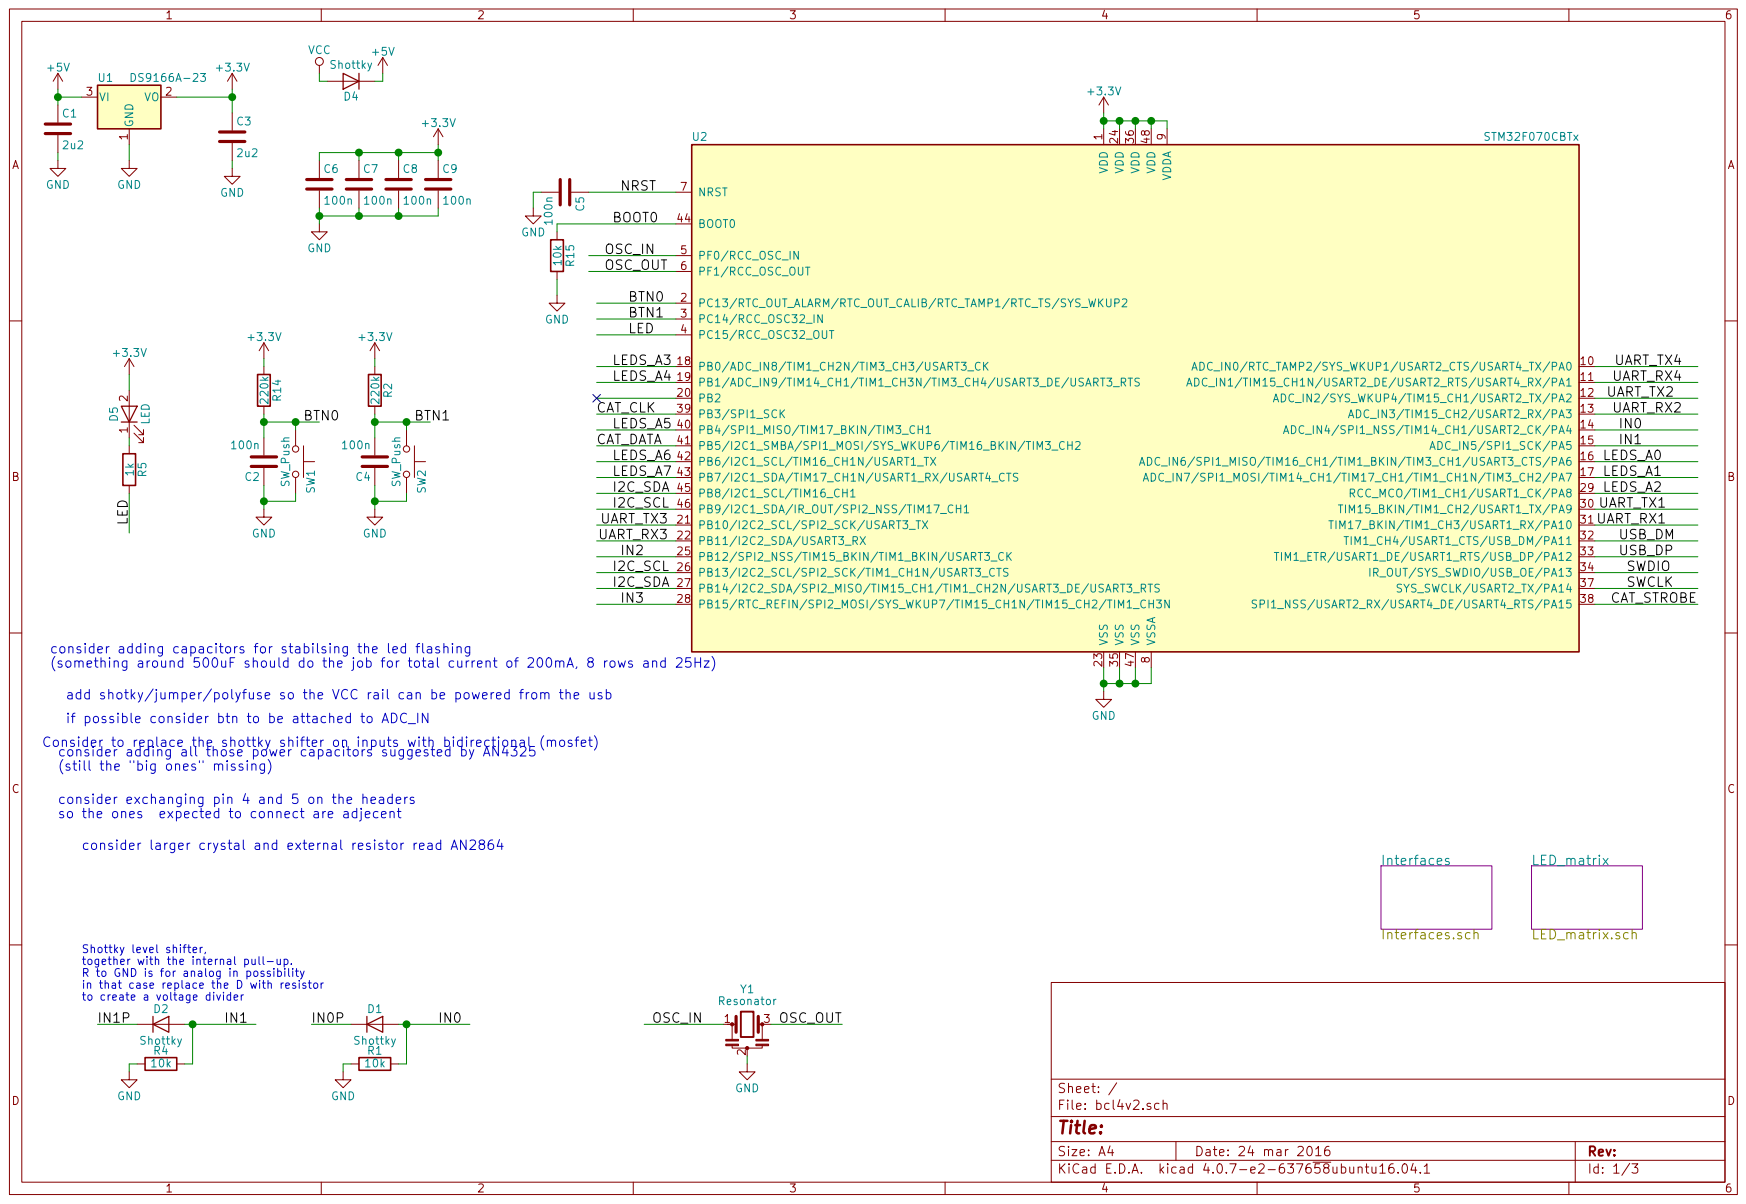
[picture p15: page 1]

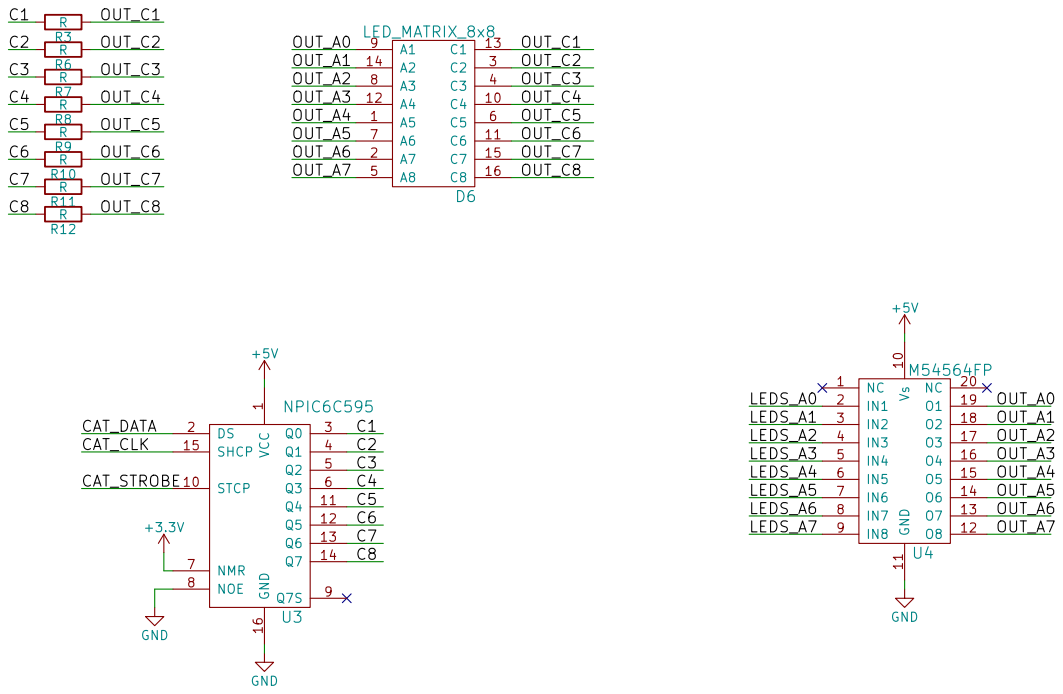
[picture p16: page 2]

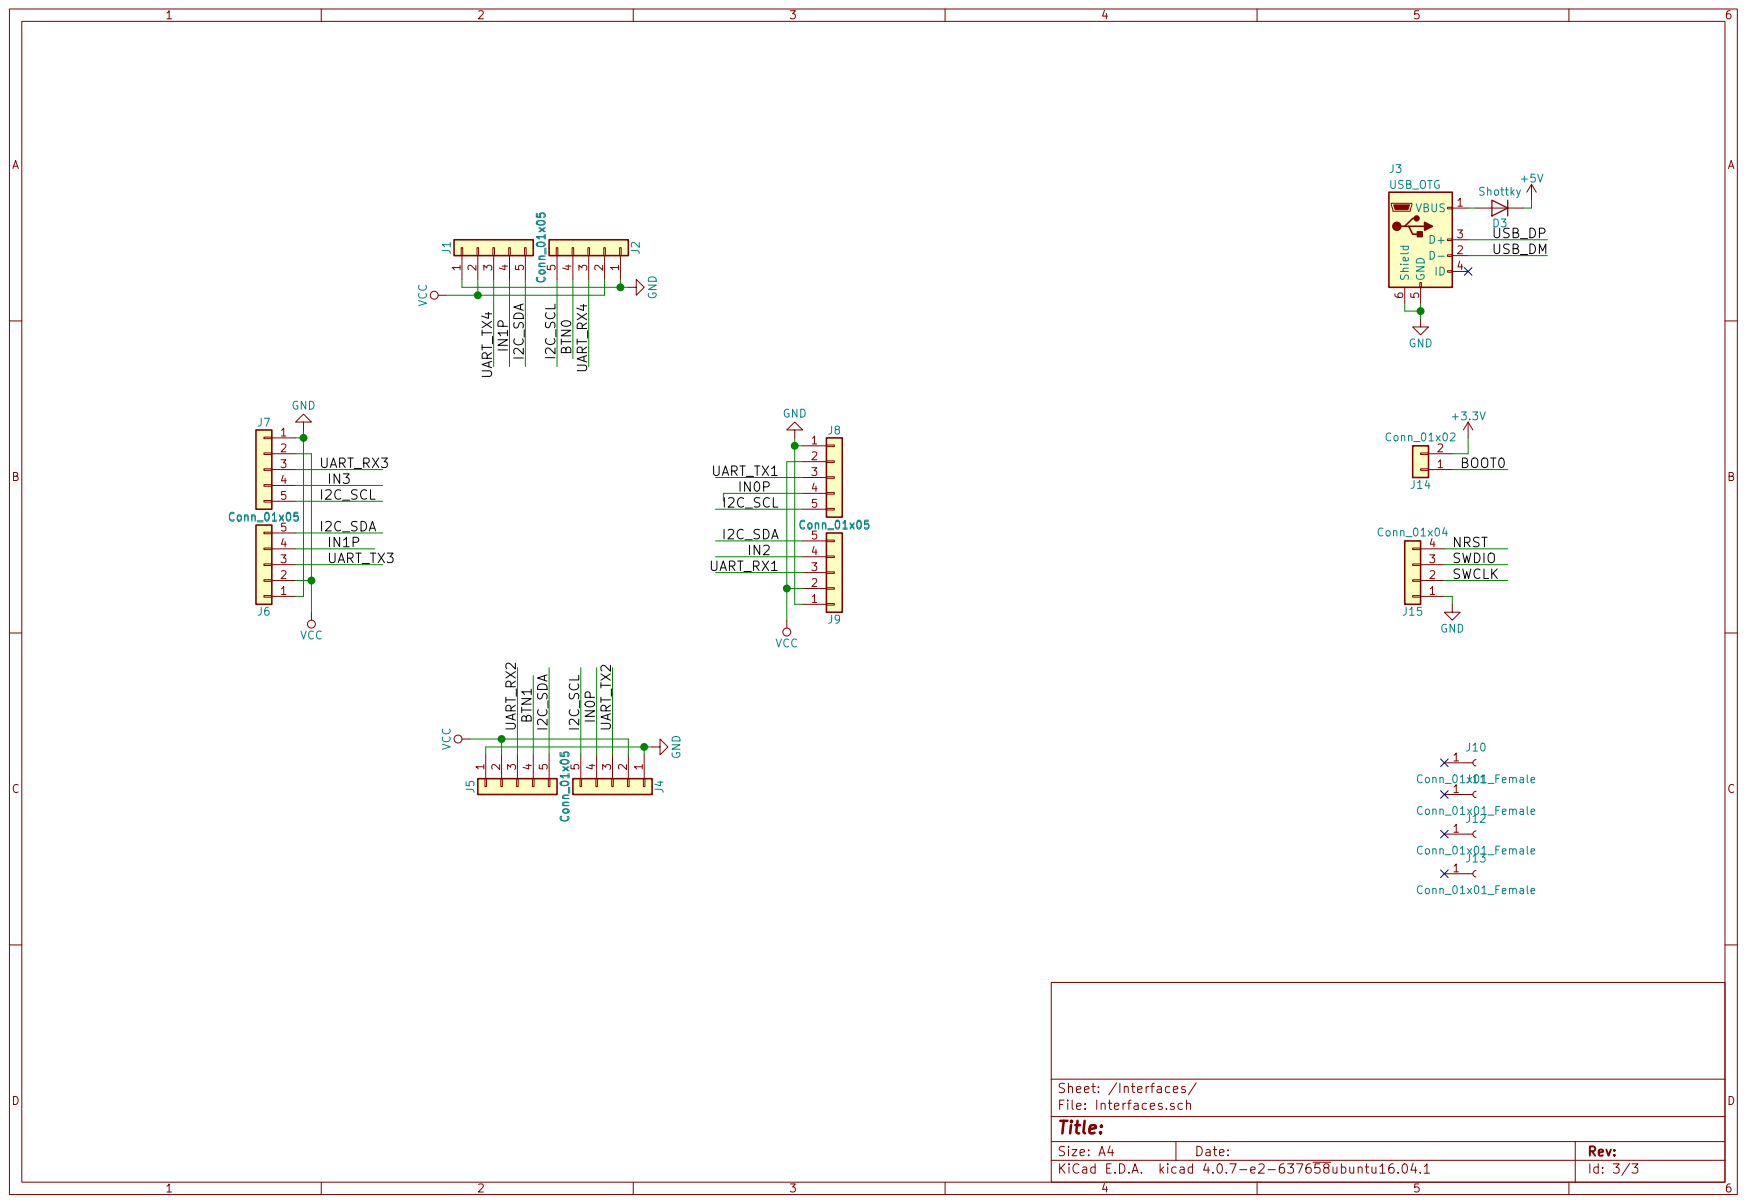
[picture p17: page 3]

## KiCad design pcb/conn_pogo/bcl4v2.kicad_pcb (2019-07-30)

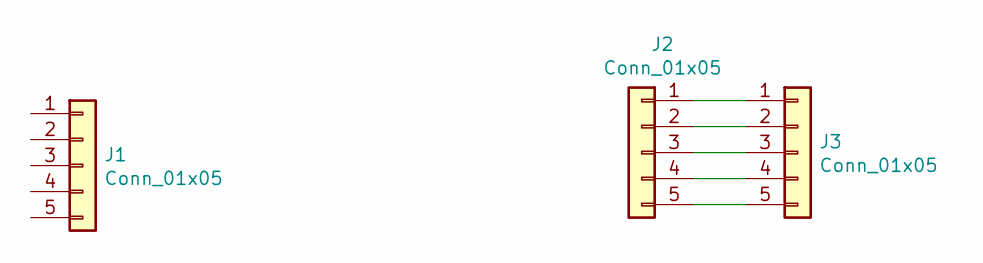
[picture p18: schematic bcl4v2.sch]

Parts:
J1: Conn_01x05; 5way_pogo_1.5mm_hole
J2, J3: Conn_01x05; 5way_pogo_pad

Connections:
unnamed: J2.1, J3.1
unnamed: J2.2, J3.2
unnamed: J2.3, J3.3
unnamed: J2.4, J3.4
unnamed: J2.5, J3.5

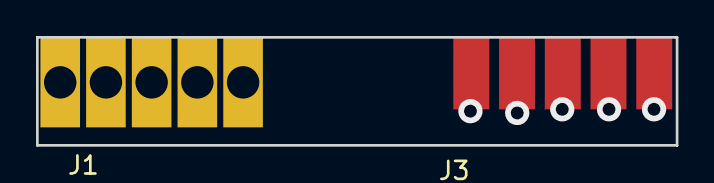
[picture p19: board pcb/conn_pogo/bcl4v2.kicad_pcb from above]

Board: 2 copper layers, 35.5 x 6.0 mm, 3 parts (1 on the bottom side), 5 nets.

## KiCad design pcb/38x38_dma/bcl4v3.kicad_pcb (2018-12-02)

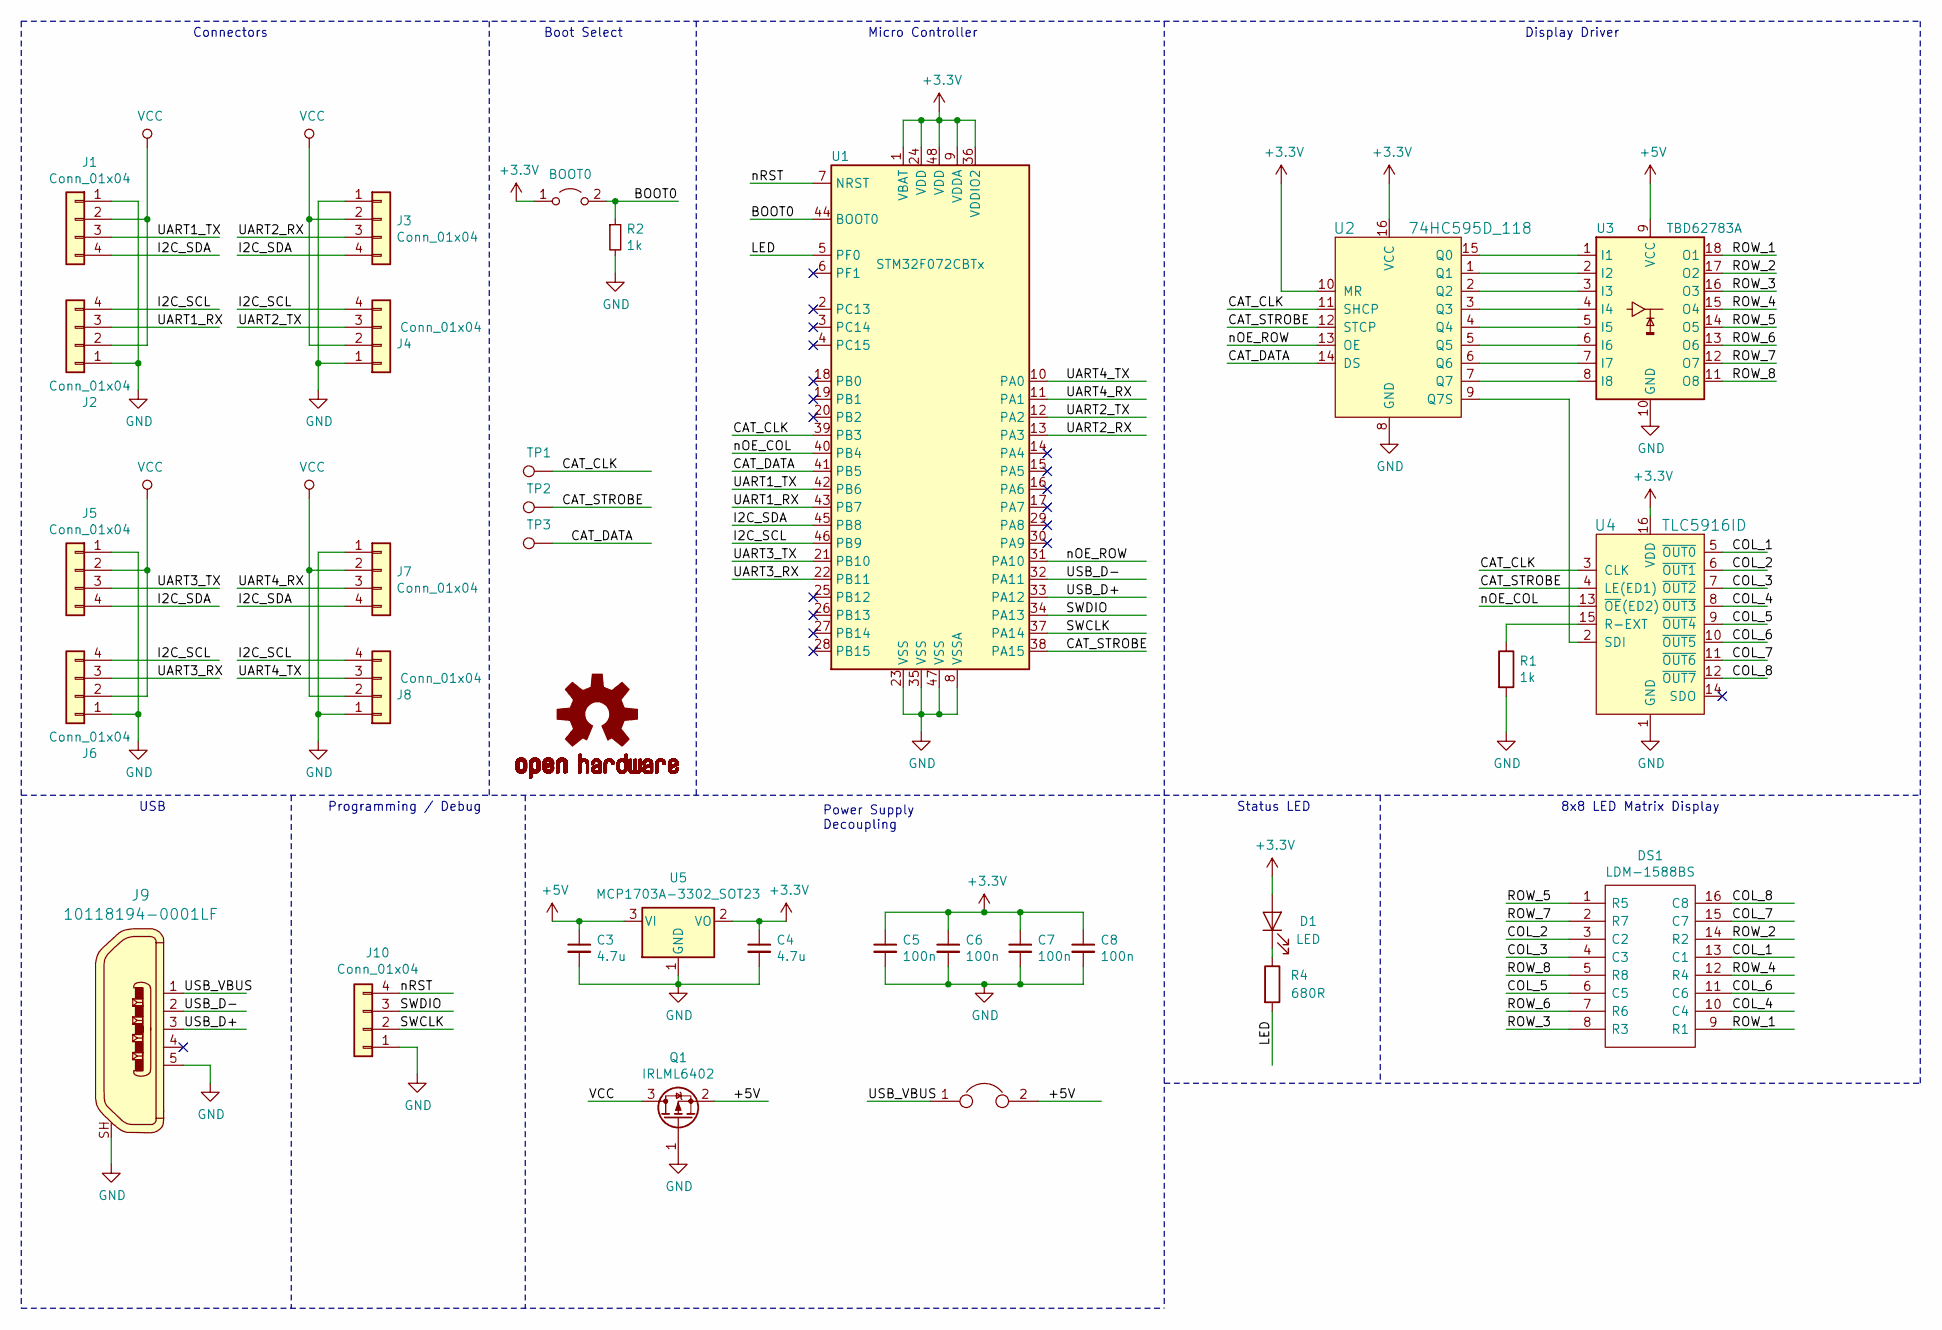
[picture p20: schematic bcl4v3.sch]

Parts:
BOOT0: Jumper_2_Open; SMT-JUMPER_2_NO_SILK
C3, C4: 4.7u; C_0805_2012Metric_Pad1.15x1.40mm_HandSolder
C5, C6, C7, C8: 100n; C_0805_2012Metric_Pad1.15x1.40mm_HandSolder
D1: LED; LED_0805_2012Metric_Castellated
DS1: LDM-1588BS; DIPS2794W50P254L3800H1065Q16N; Manufacturer_Part_Number TC15-11SRWA
J1, J2, J3, J4, J5, J6, J7, J8, J10: Conn_01x04; PinHeader_1x04_P2.54mm_Vertical
J9: 10118194-0001LF; USB_Micro_B_Female_10118194-0001LF; MPN 10118194-0001LF; Digi-Key_PN 609-4618-1-ND
JP1: Jumper; SMT-JUMPER_2_NC_TRACE_NO-SILK
LOGO1: OSHW-LOGOM; OSHW-LOGO-M
Q1: IRLML6402; SOT-23
R1, R2: 1k; R_0805_2012Metric_Pad1.15x1.40mm_HandSolder
R4: 680R; R_0805_2012Metric_Pad1.15x1.40mm_HandSolder
TP1, TP2, TP3: TestPoint; TestPoint_THTPad_1.0x1.0mm_Drill0.5mm
U1: STM32F072CBTx; LQFP-48_7x7mm_P0.5mm
U2: 74HC595D_118; TSSOP-16_4.4x5mm_P0.65mm; MPN 74HC595D,118; Digi-Key_PN 1727-2821-1-ND
U3: TBD62783A; SSOP-18_4.4x6.5mm_P0.65mm
U4: TLC5916ID; TSSOP-16_4.4x5mm_P0.65mm; MPN TLC5916ID; Digi-Key_PN 296-24383-5-ND
U5: MCP1703A-3302_SOT23; SOT-23

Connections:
+3V3: BOOT0.1 (A), C4.1, C5.1, C6.1, C7.1, C8.1, D1.2 (A), U1.1 (VBAT), U1.9 (VDDA), U1.24 (VDD), U1.36 (VDDIO2), U1.48 (VDD), U2.10 (MR), U2.16 (VCC), U4.16 (VDD), U5.2 (VO)
+5V: C3.1, JP1.2, Q1.2 (S), U3.9 (VCC), U5.3 (VI)
/BOOT0: BOOT0.2 (B), R2.1, U1.44 (BOOT0)
/CAT_CLK: TP1.1, U1.39 (PB3), U2.11 (SHCP), U4.3 (CLK)
/CAT_DATA: TP3.1, U1.41 (PB5), U2.14 (DS)
/CAT_STROBE: TP2.1, U1.38 (PA15), U2.12 (STCP), U4.4 (LE(ED1))
/COL_1: DS1.13 (C1), U4.5 (~OUT0)
/COL_2: DS1.3 (C2), U4.6 (~OUT1)
/COL_3: DS1.4 (C3), U4.7 (~OUT2)
/COL_4: DS1.10 (C4), U4.8 (~OUT3)
/COL_5: DS1.6 (C5), U4.9 (~OUT4)
/COL_6: DS1.11 (C6), U4.10 (~OUT5)
/COL_7: DS1.15 (C7), U4.11 (~OUT6)
/COL_8: DS1.16 (C8), U4.12 (~OUT7)
/I2C_SCL: J2.4, J4.4, J6.4, J8.4, U1.46 (PB9)
/I2C_SDA: J1.4, J3.4, J5.4, J7.4, U1.45 (PB8)
/LED: R4.2, U1.5 (PF0)
/ROW_1: DS1.9 (R1), U3.18 (O1)
/ROW_2: DS1.14 (R2), U3.17 (O2)
/ROW_3: DS1.8 (R3), U3.16 (O3)
/ROW_4: DS1.12 (R4), U3.15 (O4)
/ROW_5: DS1.1 (R5), U3.14 (O5)
/ROW_6: DS1.7 (R6), U3.13 (O6)
/ROW_7: DS1.2 (R7), U3.12 (O7)
/ROW_8: DS1.5 (R8), U3.11 (O8)
/SWCLK: J10.2, U1.37 (PA14)
/SWDIO: J10.3, U1.34 (PA13)
/UART1_RX: J2.3, U1.43 (PB7)
/UART1_TX: J1.3, U1.42 (PB6)
/UART2_RX: J3.3, U1.13 (PA3)
/UART2_TX: J4.3, U1.12 (PA2)
/UART3_RX: J6.3, U1.22 (PB11)
/UART3_TX: J5.3, U1.21 (PB10)
/UART4_RX: J7.3, U1.11 (PA1)
/UART4_TX: J8.3, U1.10 (PA0)
/USB_D+: J9.3, U1.33 (PA12)
/USB_D-: J9.2, U1.32 (PA11)
/USB_VBUS: J9.1, JP1.1
/nOE_COL: U1.40 (PB4), U4.13 (~OE~(ED2))
/nOE_ROW: U1.31 (PA10), U2.13 (OE)
/nRST: J10.4, U1.7 (NRST)
GND: C3.2, C4.2, C5.2, C6.2, C7.2, C8.2, J1.1, J2.1, J3.1, J4.1, J5.1, J6.1, J7.1, J8.1, J9.5, J9.SH, J10.1, Q1.1 (G), R1.2, R2.2, U1.8 (VSSA), U1.23 (VSS), U1.35 (VSS), U1.47 (VSS), U2.8 (GND), U3.10 (GND), U4.1 (GND), U5.1 (GND)
unnamed: D1.1 (K), R4.1
unnamed: R1.1, U4.15 (R-EXT)
unnamed: U2.1 (Q1), U3.2 (I2)
unnamed: U2.2 (Q2), U3.3 (I3)
unnamed: U2.3 (Q3), U3.4 (I4)
unnamed: U2.4 (Q4), U3.5 (I5)
unnamed: U2.5 (Q5), U3.6 (I6)
unnamed: U2.6 (Q6), U3.7 (I7)
unnamed: U2.7 (Q7), U3.8 (I8)
unnamed: U2.9 (Q7S), U4.2 (SDI)
unnamed: U2.15 (Q0), U3.1 (I1)
VCC: J1.2, J2.2, J3.2, J4.2, J5.2, J6.2, J7.2, J8.2, Q1.3 (D)

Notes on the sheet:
8x8 LED Matrix Display
Status LED
Display Driver
Micro Controller
Power Supply Decoupling
Boot Select
Connectors
USB
Programming / Debug

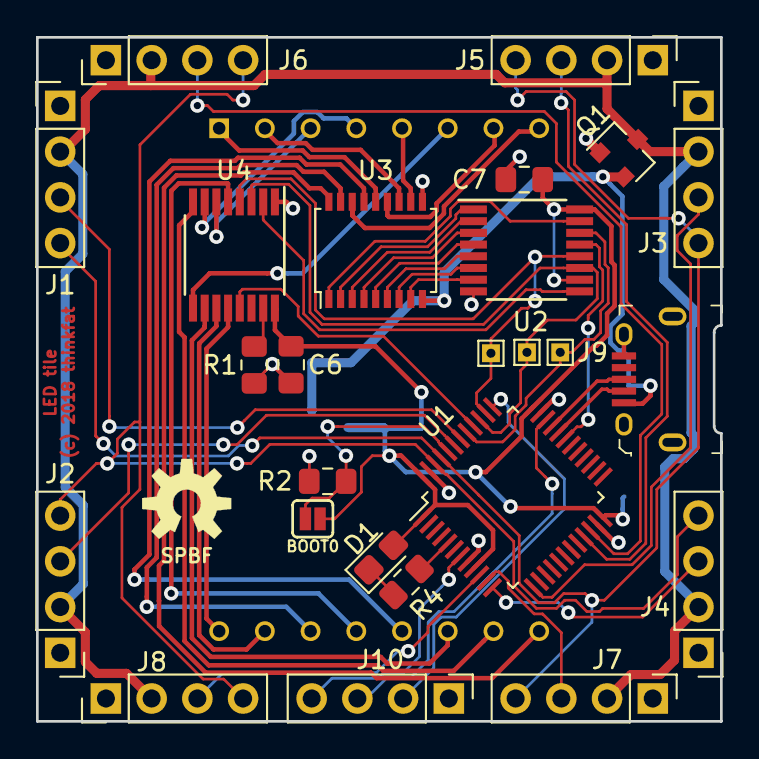
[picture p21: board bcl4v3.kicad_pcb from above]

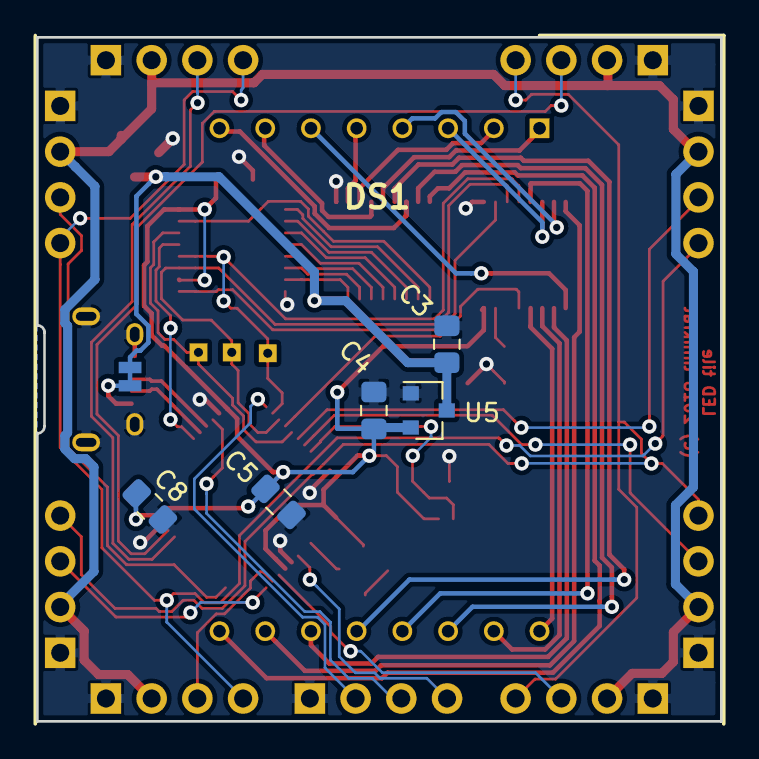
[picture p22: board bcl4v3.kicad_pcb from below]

Board: 2 copper layers, 38.0 x 38.0 mm, 33 parts (7 on the bottom side), 54 nets.

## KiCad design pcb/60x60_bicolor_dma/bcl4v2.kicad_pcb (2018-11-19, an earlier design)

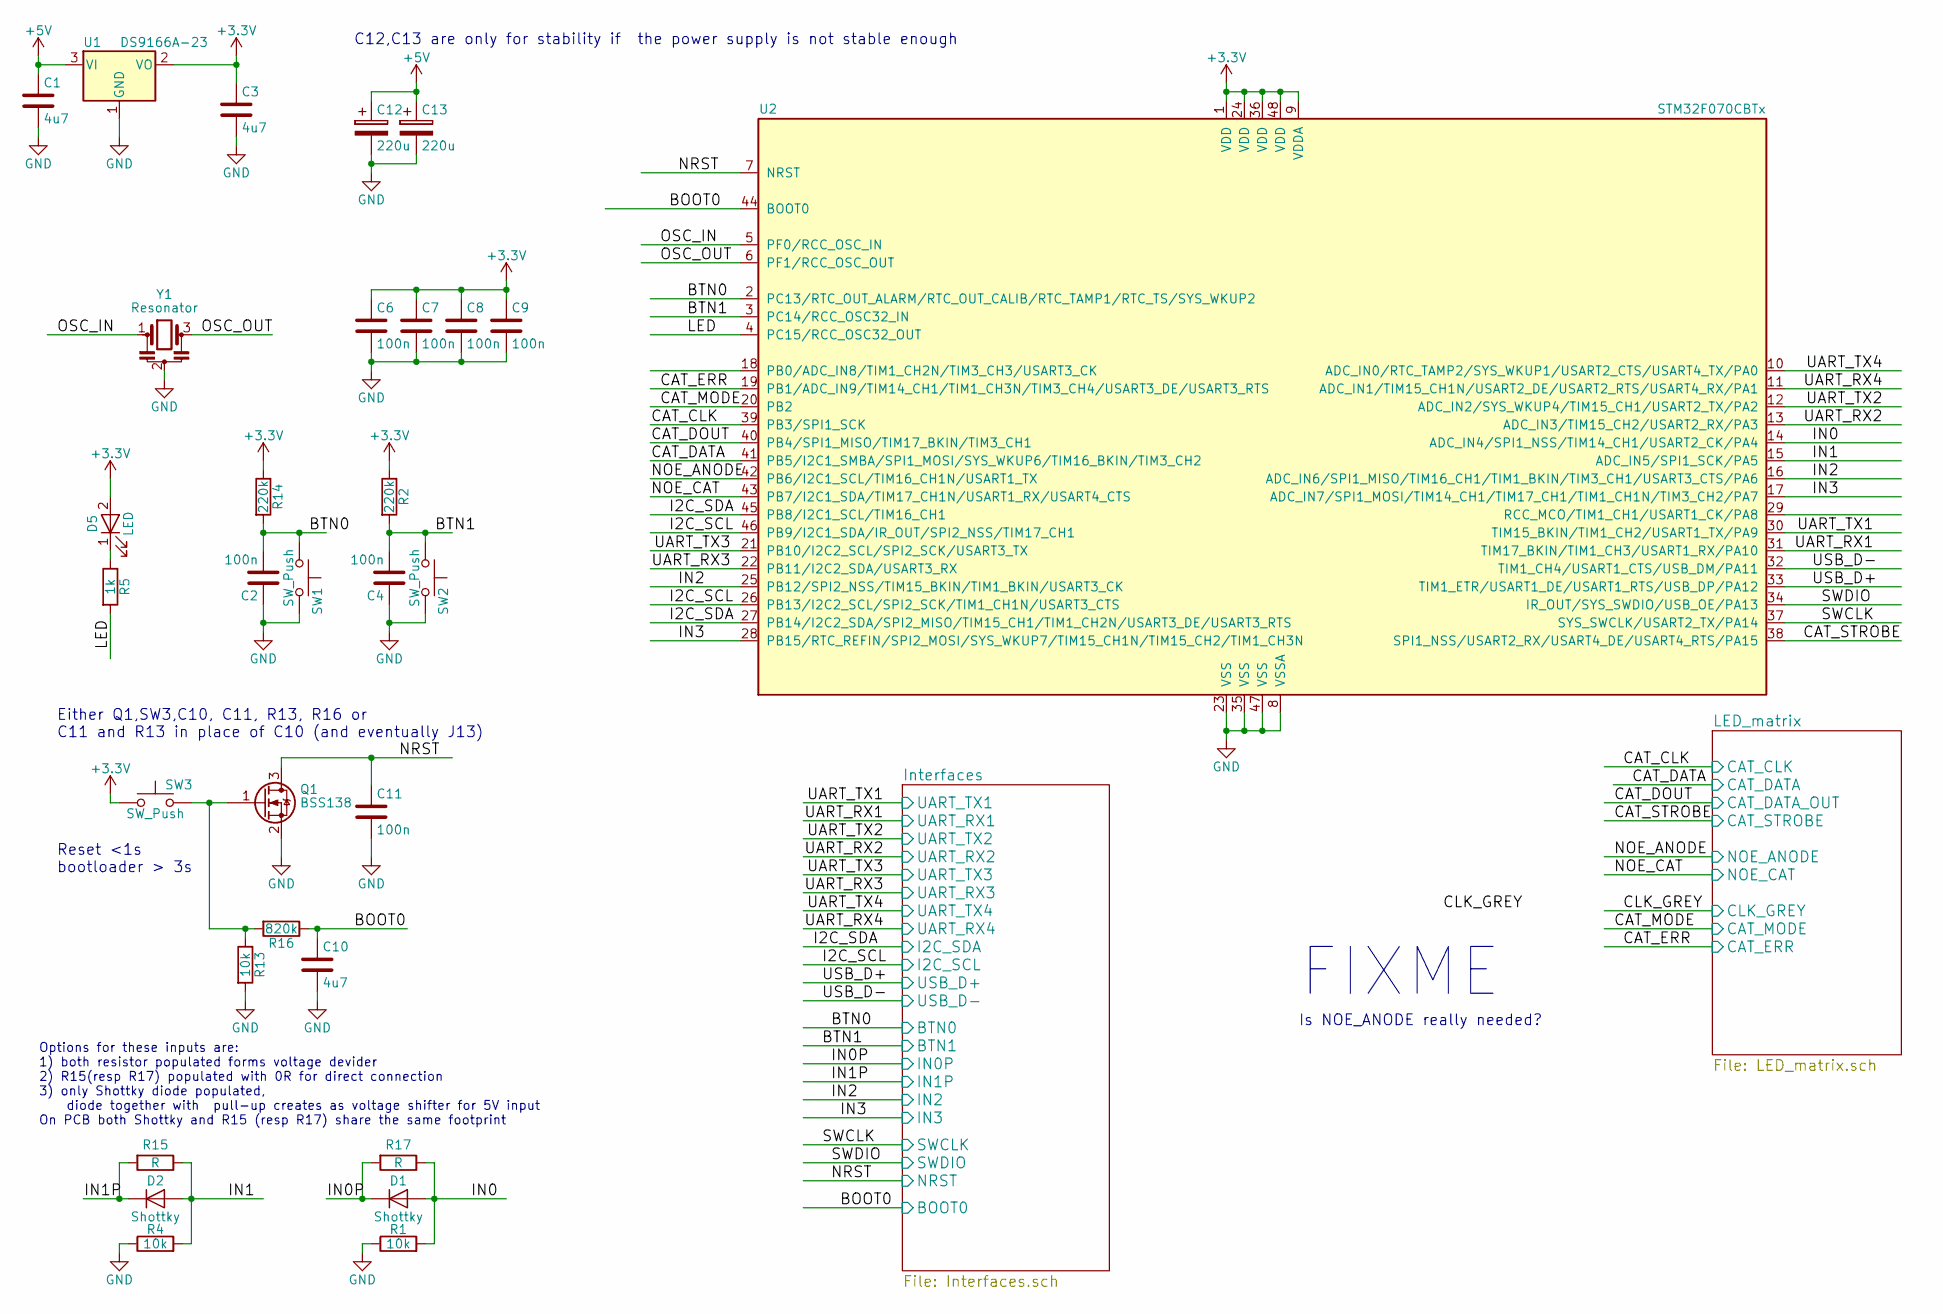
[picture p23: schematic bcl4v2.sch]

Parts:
C1, C3, C10: 4u7; C_0805_HandSoldering
C2, C4, C11: 100n; C_0805_HandSoldering
C6, C7, C8, C9: 100n; C_0603_HandSoldering
C12, C13: 220u; CP_Tantalum_Case-V_EIA-7343-20_Hand
D1, D2: Shottky; badger_D_SOD-123_hand
D5: LED; LED_0805_HandSoldering
Q1: BSS138; badger_SOT-23_handsolder
R1, R4, R13: 10k; R_0805_HandSoldering
R2, R14: 220k; R_0805_HandSoldering
R5: 1k; R_0805_HandSoldering
R15, R17: R; R_0805_HandSoldering
R16: 820k; R_0805_HandSoldering
SW1, SW2, SW3: SW_Push; badger_smd_button_KSS231G
U1: DS9166A-23; badger_SOT-23_handsolder
U2: STM32F070CBTx; badger_LQFP-48_7x7mm_Pitch0.5mm_handsolder
Y1: Resonator; badger_CSTCE_G

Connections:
+3V3: C3.1, C6.1, C7.1, C8.1, C9.1, D5.2 (A), R2.1, R14.1, SW3.1, U1.2 (VO), U2.1 (VDD), U2.9 (VDDA), U2.24 (VDD), U2.36 (VDD), U2.48 (VDD); also elsewhere on the board
+5V: C1.1, C12.1, C13.1, U1.3 (VI); also elsewhere on the board
/BOOT0: C10.1, R16.1, U2.44 (BOOT0); also elsewhere on the board
/BTN0: C2.2, R14.2, SW1.1, U2.2 (PC13/RTC_OUT_ALARM/RTC_OUT_CALIB/RTC_TA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); also elsewhere on the board
/BTN1: C4.2, R2.2, SW2.1, U2.3 (PC14/RCC_OSC32_IN); also elsewhere on the board
/CAT_CLK: U2.39 (PB3/SPI1_SCK); also elsewhere on the board
/CAT_DATA: U2.41 (PB5/I2C1_SMBA/SPI1_MOSI/SYS_WKUP6/TIM16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); also elsewhere on the board
/CAT_DOUT: U2.40 (PB4/SPI1_MISO/TIM17_BKIN/TIM3_CH1); also elsewhere on the board
/CAT_ERR: U2.19 (PB1/ADC_IN9/TIM14_CH1/TIM1_CH3N/TIM3_CH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); also elsewhere on the board
/CAT_MODE: U2.20 (PB2); also elsewhere on the board
/CAT_STROBE: U2.38 (SPI1_NSS/USART2_RX/USART4_DE/USART4_RTS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); also elsewhere on the board
/I2C_SCL: U2.26 (PB13/I2C2_SCL/SPI2_SCK/TIM1_CH1N/USART3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), U2.46 (PB9/I2C1_SDA/IR_OUT/SPI2_NSS/TIM17_CH1); also elsewhere on the board
/I2C_SDA: U2.27 (PB14/I2C2_SDA/SPI2_MISO/TIM15_CH1/TIM1_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), U2.45 (PB8/I2C1_SCL/TIM16_CH1); also elsewhere on the board
/IN0: D1.2 (A), R1.2, R17.1, U2.14 (ADC_IN4/SPI1_NSS/TIM14_CH1/USART2_CK/PA4)
/IN0P: D1.1 (K), R17.2; also elsewhere on the board
/IN1: D2.2 (A), R4.2, R15.1, U2.15 (ADC_IN5/SPI1_SCK/PA5)
/IN1P: D2.1 (K), R15.2; also elsewhere on the board
/IN2: U2.16 (ADC_IN6/SPI1_MISO/TIM16_CH1/TIM1_BKIN/T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), U2.25 (PB12/SPI2_NSS/TIM15_BKIN/TIM1_BKIN/USAR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); also elsewhere on the board
/IN3: U2.17 (ADC_IN7/SPI1_MOSI/TIM14_CH1/TIM17_CH1/T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), U2.28 (PB15/RTC_REFIN/SPI2_MOSI/SYS_WKUP7/TIM1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); also elsewhere on the board
/LED: R5.2, U2.4 (PC15/RCC_OSC32_OUT)
/NOE_ANODE: U2.42 (PB6/I2C1_SCL/TIM16_CH1N/USART1_TX); also elsewhere on the board
/NOE_CAT: U2.43 (PB7/I2C1_SDA/TIM17_CH1N/USART1_RX/USART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); also elsewhere on the board
/NRST: C11.1, Q1.3 (D), U2.7 (NRST); also elsewhere on the board
/OSC_IN: U2.5 (PF0/RCC_OSC_IN), Y1.1
/OSC_OUT: U2.6 (PF1/RCC_OSC_OUT), Y1.3
/SWCLK: U2.37 (SYS_SWCLK/USART2_TX/PA14); also elsewhere on the board
/SWDIO: U2.34 (IR_OUT/SYS_SWDIO/USB_OE/PA13); also elsewhere on the board
/UART_RX1: U2.31 (TIM17_BKIN/TIM1_CH3/USART1_RX/PA10); also elsewhere on the board
/UART_RX2: U2.13 (ADC_IN3/TIM15_CH2/USART2_RX/PA3); also elsewhere on the board
/UART_RX3: U2.22 (PB11/I2C2_SDA/USART3_RX); also elsewhere on the board
/UART_RX4: U2.11 (ADC_IN1/TIM15_CH1N/USART2_DE/USART2_RTS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); also elsewhere on the board
/UART_TX1: U2.30 (TIM15_BKIN/TIM1_CH2/USART1_TX/PA9); also elsewhere on the board
/UART_TX2: U2.12 (ADC_IN2/SYS_WKUP4/TIM15_CH1/USART2_TX/P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); also elsewhere on the board
/UART_TX3: U2.21 (PB10/I2C2_SCL/SPI2_SCK/USART3_TX); also elsewhere on the board
/UART_TX4: U2.10 (ADC_IN0/RTC_TAMP2/SYS_WKUP1/USART2_CTS/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); also elsewhere on the board
/USB_D+: U2.33 (TIM1_ETR/USART1_DE/USART1_RTS/USB_DP/PA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); also elsewhere on the board
/USB_D-: U2.32 (TIM1_CH4/USART1_CTS/USB_DM/PA11); also elsewhere on the board
GND: C1.2, C2.1, C3.2, C4.1, C6.2, C7.2, C8.2, C9.2, C10.2, C11.2, C12.2, C13.2, Q1.2 (S), R1.1, R4.1, R13.2, SW1.2, SW2.2, U1.1 (GND), U2.8 (VSSA), U2.23 (VSS), U2.35 (VSS), U2.47 (VSS), Y1.2; also elsewhere on the board
unnamed: D5.1 (K), R5.1
unnamed: Q1.1 (G), R13.1, R16.2, SW3.2

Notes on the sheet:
Options for these inputs are: 1) both resistor populated forms voltage devider 2) R15(resp R17) populated with 0R for direct connection 3) only Shottky diode populated, diode together with pull-up creates as voltage shifter for 5V input On PCB both Shottky and R15 (resp R17) share the same footprint
Reset <1s bootloader > 3s
Either Q1,SW3,C10, C11, R13, R16 or C11 and R13 in place of C10 (and eventually J13)
C12,C13 are only for stability if the power supply is not stable enough
FIXME
Is NOE_ANODE really needed?

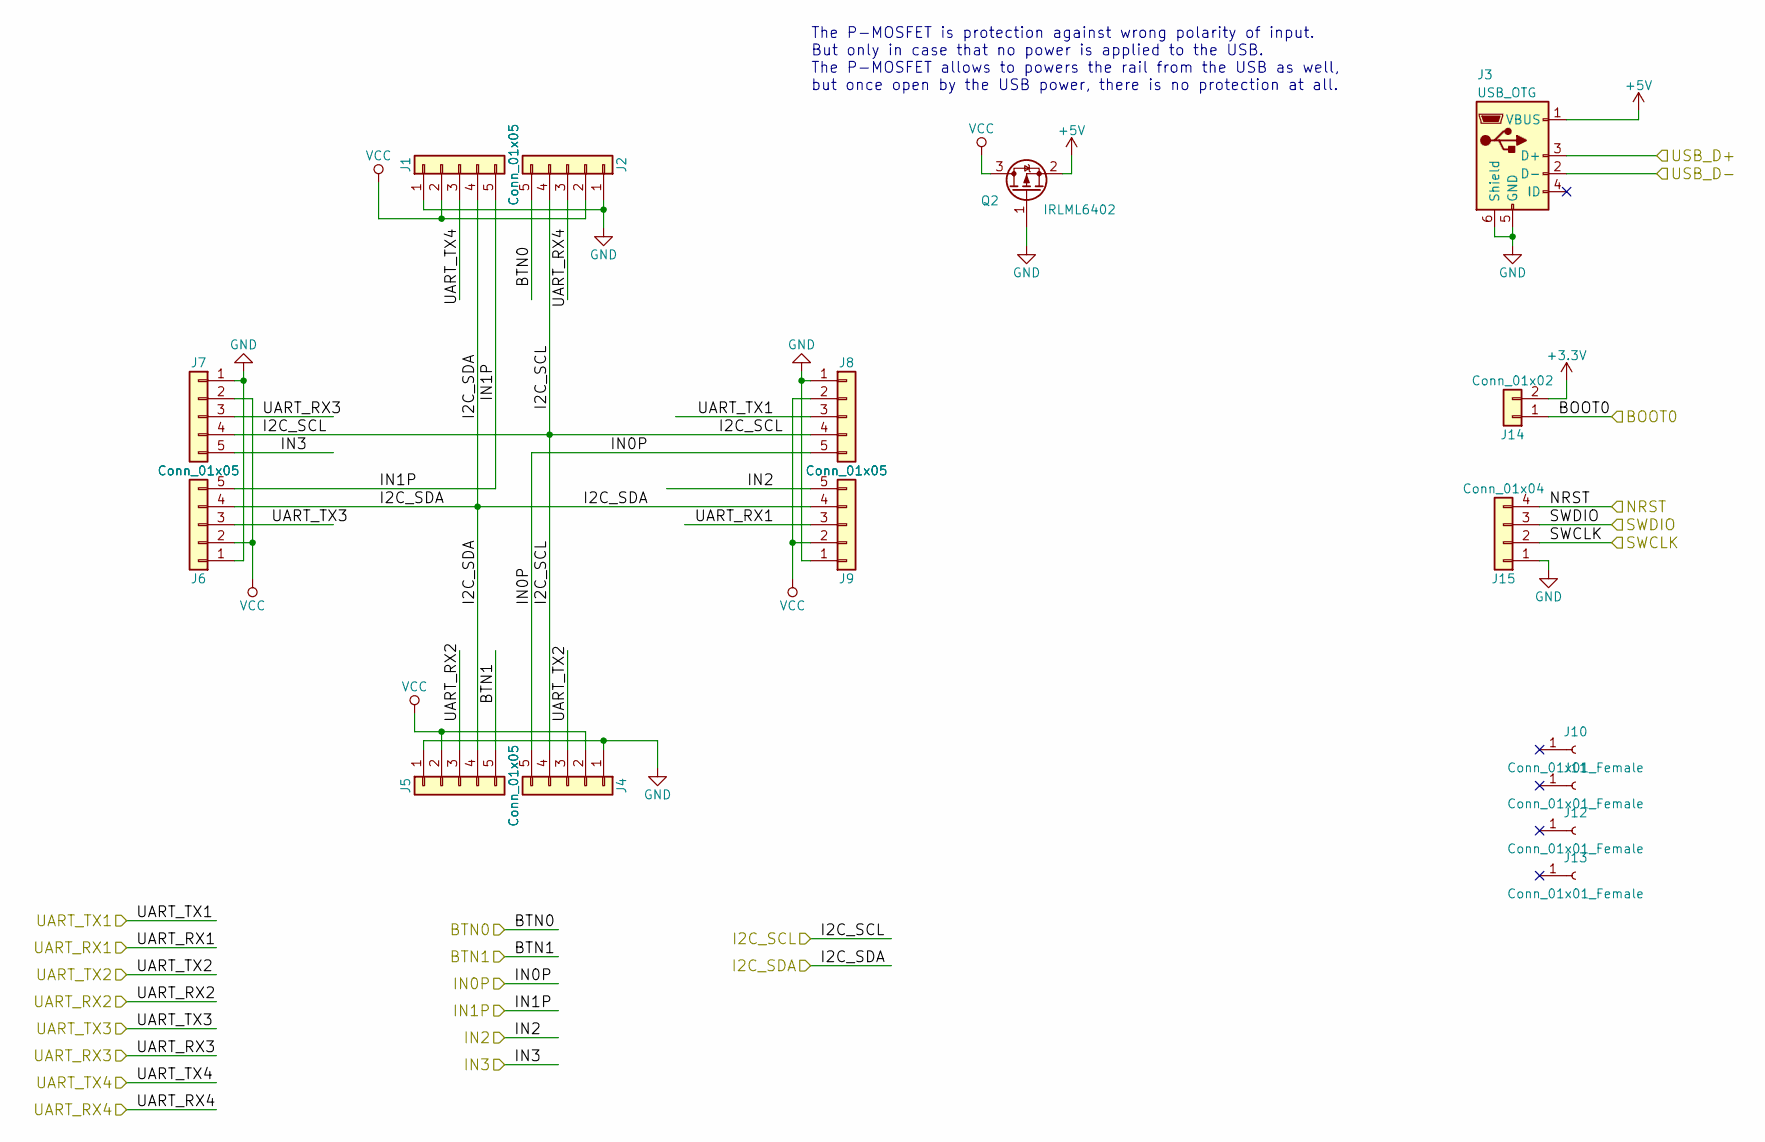
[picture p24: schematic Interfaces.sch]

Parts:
J1, J2, J4, J5, J6, J7, J8, J9: Conn_01x05; badger_Pin_Hdr_1x05_2.54mm_handsolder
J3: USB_OTG; USB_Micro-B
J10, J11, J12, J13: Conn_01x01_Female; badger_mount_M3
J14: Conn_01x02; badger_Pin_Hdr_1x02_2.54mm_angled_handsolder
J15: Conn_01x04; badger_Pin_Hdr_1x04_2.54mm_angled_handsolder
Q2: IRLML6402; badger_SOT-23_handsolder

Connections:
+3V3: J14.2; also elsewhere on the board
+5V: J3.1 (VBUS), Q2.2 (S); also elsewhere on the board
/BOOT0: J14.1; also elsewhere on the board
/BTN0: J2.5; also elsewhere on the board
/BTN1: J5.5; also elsewhere on the board
/I2C_SCL: J2.4, J4.4, J7.4, J8.4; also elsewhere on the board
/I2C_SDA: J1.4, J5.4, J6.4, J9.4; also elsewhere on the board
/IN0P: J4.5, J8.5; also elsewhere on the board
/IN1P: J1.5, J6.5; also elsewhere on the board
/IN2: J9.5; also elsewhere on the board
/IN3: J7.5; also elsewhere on the board
/NRST: J15.4; also elsewhere on the board
/SWCLK: J15.2; also elsewhere on the board
/SWDIO: J15.3; also elsewhere on the board
/UART_RX1: J9.3; also elsewhere on the board
/UART_RX2: J5.3; also elsewhere on the board
/UART_RX3: J7.3; also elsewhere on the board
/UART_RX4: J2.3; also elsewhere on the board
/UART_TX1: J8.3; also elsewhere on the board
/UART_TX2: J4.3; also elsewhere on the board
/UART_TX3: J6.3; also elsewhere on the board
/UART_TX4: J1.3; also elsewhere on the board
/USB_D+: J3.3 (D+); also elsewhere on the board
/USB_D-: J3.2 (D-); also elsewhere on the board
GND: J1.1, J2.1, J3.5 (GND), J3.6 (Shield), J4.1, J5.1, J6.1, J7.1, J8.1, J9.1, J15.1, Q2.1 (G); also elsewhere on the board
VCC: J1.2, J2.2, J4.2, J5.2, J6.2, J7.2, J8.2, J9.2, Q2.3 (D)

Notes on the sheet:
The P-MOSFET is protection against wrong polarity of input. But only in case that no power is applied to the USB. The P-MOSFET allows to powers the rail from the USB as well, but once open by the USB power, there is no protection at all.

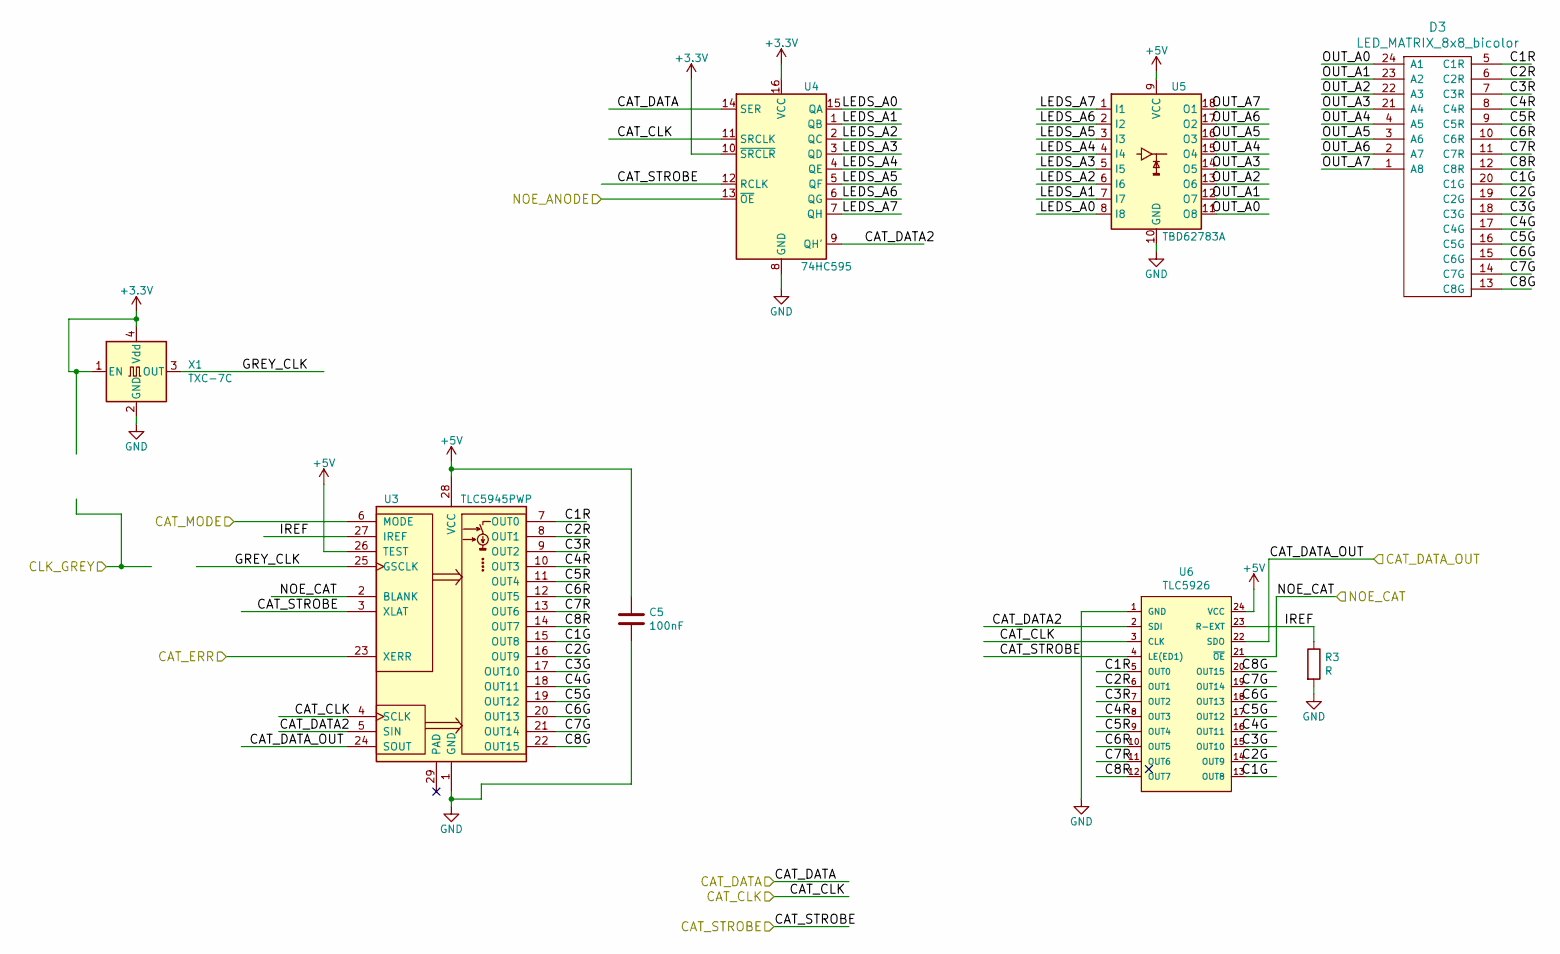
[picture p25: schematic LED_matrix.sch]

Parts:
C5: 100nF; C_0805_HandSoldering
D3: LED_MATRIX_8x8_bicolor; badger_LED_MATRIX_8x8_60.2mmx60.2mm_bicolor
R3: R; R_0805_HandSoldering
U3: TLC5945PWP; HTSSOP-28_4.4x9.7mm_Pitch0.65mm_wo_thermal_pad
U4: 74HC595; SO-16-N
U5: TBD62783A; SOIC-18W_7.5x11.6mm_Pitch1.27mm
U6: TLC5926; SOIC-24W_7.5x15.4mm_Pitch1.27mm
X1: TXC-7C; Oscillator_SMD_EuroQuartz_XO53-4pin_5.0x3.2mm_HandSoldering

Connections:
+3V3: U4.10 (~SRCLR), U4.16 (VCC), X1.1 (EN), X1.4 (Vdd); also elsewhere on the board
+5V: C5.1, U3.26 (TEST), U3.28 (VCC), U5.9 (VCC), U6.24 (VCC); also elsewhere on the board
/CAT_CLK: U3.4 (SCLK), U4.11 (SRCLK), U6.3 (CLK); also elsewhere on the board
/CAT_DATA: U4.14 (SER); also elsewhere on the board
/CAT_DOUT: U3.24 (SOUT), U6.22 (SDO); also elsewhere on the board
/CAT_ERR: U3.23 (XERR); also elsewhere on the board
/CAT_MODE: U3.6 (MODE); also elsewhere on the board
/CAT_STROBE: U3.3 (XLAT), U4.12 (RCLK), U6.4 (LE(ED1)); also elsewhere on the board
/LED_matrix/C1G: D3.20 (C1G), U3.15 (OUT8), U6.13 (OUT8)
/LED_matrix/C1R: D3.5 (C1R), U3.7 (OUT0), U6.5 (OUT0)
/LED_matrix/C2G: D3.19 (C2G), U3.16 (OUT9), U6.14 (OUT9)
/LED_matrix/C2R: D3.6 (C2R), U3.8 (OUT1), U6.6 (OUT1)
/LED_matrix/C3G: D3.18 (C3G), U3.17 (OUT10), U6.15 (OUT10)
/LED_matrix/C3R: D3.7 (C3R), U3.9 (OUT2), U6.7 (OUT2)
/LED_matrix/C4G: D3.17 (C4G), U3.18 (OUT11), U6.16 (OUT11)
/LED_matrix/C4R: D3.8 (C4R), U3.10 (OUT3), U6.8 (OUT3)
/LED_matrix/C5G: D3.16 (C5G), U3.19 (OUT12), U6.17 (OUT12)
/LED_matrix/C5R: D3.9 (C5R), U3.11 (OUT4), U6.9 (OUT4)
/LED_matrix/C6G: D3.15 (C6G), U3.20 (OUT13), U6.18 (OUT13)
/LED_matrix/C6R: D3.10 (C6R), U3.12 (OUT5), U6.10 (OUT5)
/LED_matrix/C7G: D3.14 (C7G), U3.21 (OUT14), U6.19 (OUT14)
/LED_matrix/C7R: D3.11 (C7R), U3.13 (OUT6), U6.11 (OUT6)
/LED_matrix/C8G: D3.13 (C8G), U3.22 (OUT15), U6.20 (OUT15)
/LED_matrix/C8R: D3.12 (C8R), U3.14 (OUT7), U6.12 (OUT7)
/LED_matrix/CAT_DATA2: U3.5 (SIN), U4.9 (QH'), U6.2 (SDI)
/LED_matrix/GREY_CLK: U3.25 (GSCLK), X1.3 (OUT)
/LED_matrix/IREF: R3.1, U3.27 (IREF), U6.23 (R-EXT)
/LED_matrix/LEDS_A0: U4.15 (QA), U5.8 (I8)
/LED_matrix/LEDS_A1: U4.1 (QB), U5.7 (I7)
/LED_matrix/LEDS_A2: U4.2 (QC), U5.6 (I6)
/LED_matrix/LEDS_A3: U4.3 (QD), U5.5 (I5)
/LED_matrix/LEDS_A4: U4.4 (QE), U5.4 (I4)
/LED_matrix/LEDS_A5: U4.5 (QF), U5.3 (I3)
/LED_matrix/LEDS_A6: U4.6 (QG), U5.2 (I2)
/LED_matrix/LEDS_A7: U4.7 (QH), U5.1 (I1)
/LED_matrix/OUT_A0: D3.24 (A1), U5.11 (O8)
/LED_matrix/OUT_A1: D3.23 (A2), U5.12 (O7)
/LED_matrix/OUT_A2: D3.22 (A3), U5.13 (O6)
/LED_matrix/OUT_A3: D3.21 (A4), U5.14 (O5)
/LED_matrix/OUT_A4: D3.4 (A5), U5.15 (O4)
/LED_matrix/OUT_A5: D3.3 (A6), U5.16 (O3)
/LED_matrix/OUT_A6: D3.2 (A7), U5.17 (O2)
/LED_matrix/OUT_A7: D3.1 (A8), U5.18 (O1)
/NOE_ANODE: U4.13 (~OE); also elsewhere on the board
/NOE_CAT: U3.2 (BLANK), U6.21 (~OE); also elsewhere on the board
GND: C5.2, R3.2, U3.1 (GND), U4.8 (GND), U5.10 (GND), U6.1 (GND), X1.2 (GND); also elsewhere on the board

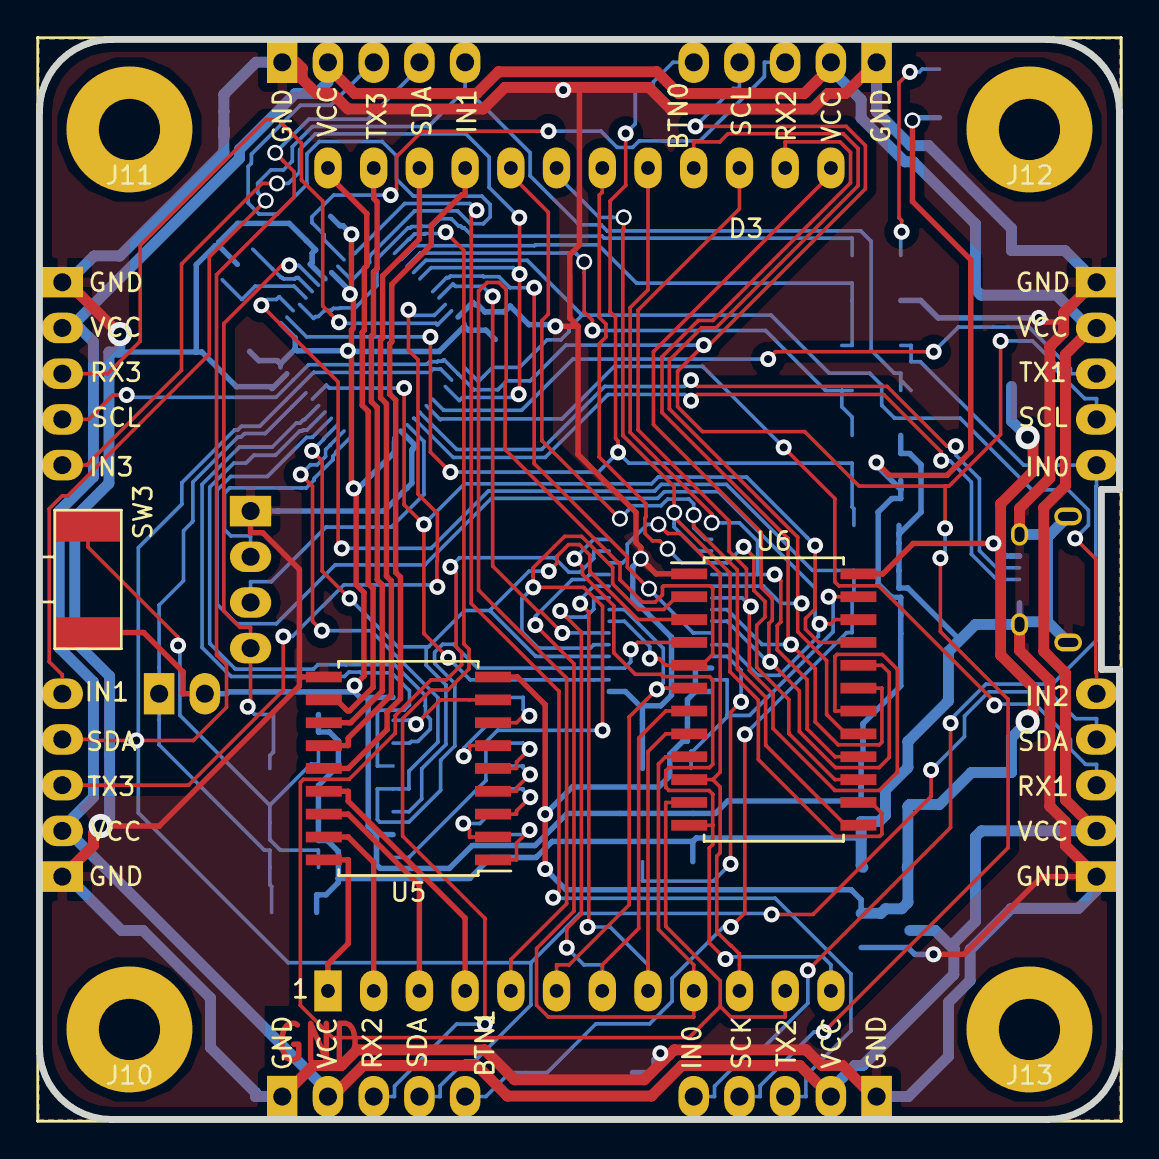
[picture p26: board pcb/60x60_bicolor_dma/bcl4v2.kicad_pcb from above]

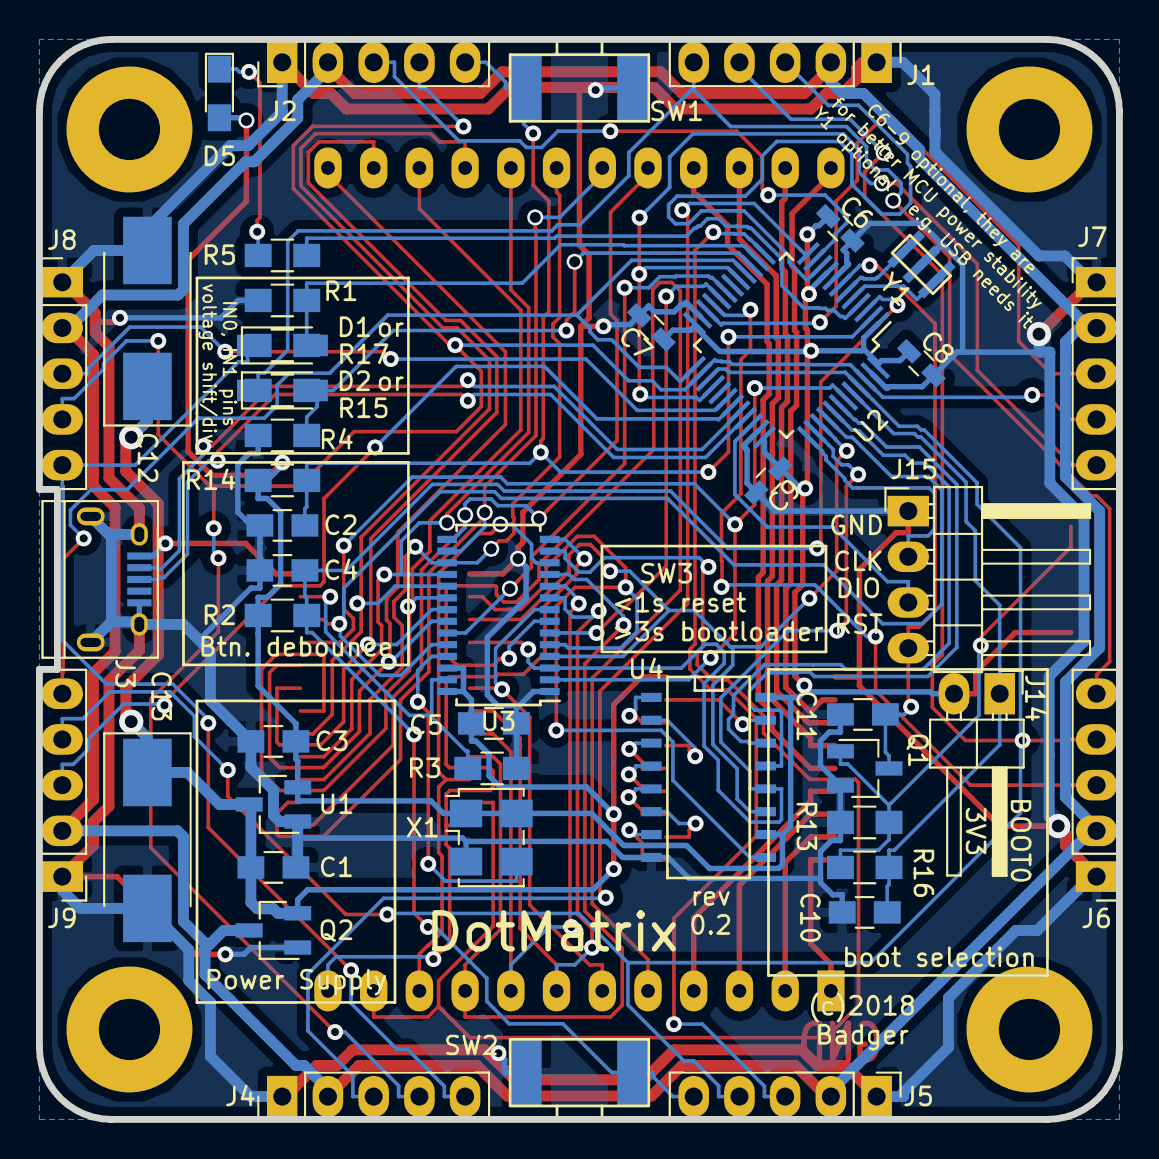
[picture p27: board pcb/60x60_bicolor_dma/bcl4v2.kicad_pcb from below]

Board: 2 copper layers, 60.0 x 60.0 mm, 55 parts (47 on the bottom side), 76 nets.

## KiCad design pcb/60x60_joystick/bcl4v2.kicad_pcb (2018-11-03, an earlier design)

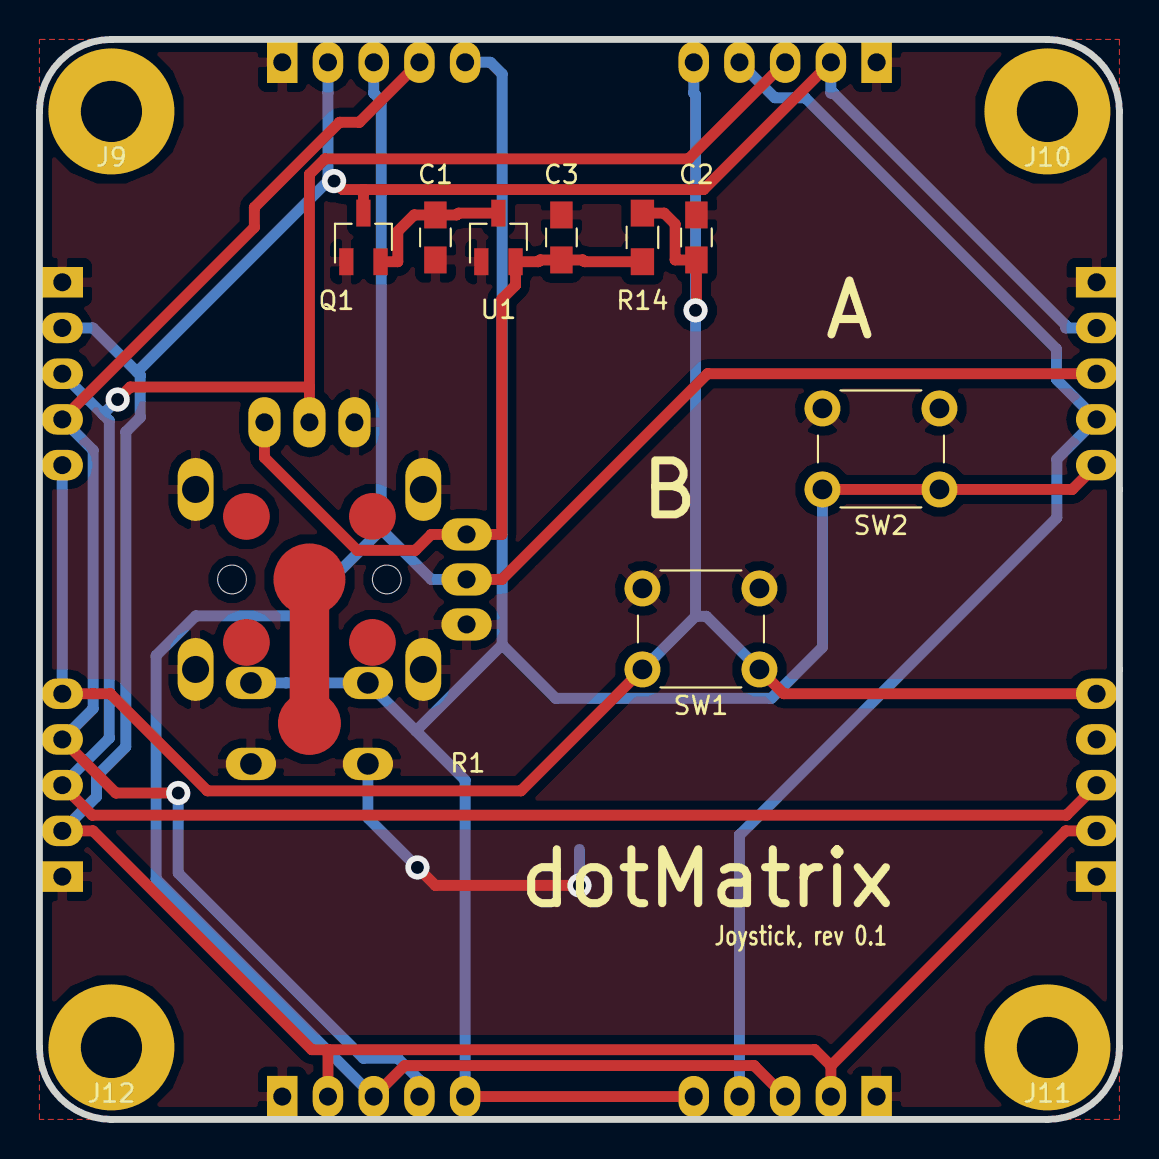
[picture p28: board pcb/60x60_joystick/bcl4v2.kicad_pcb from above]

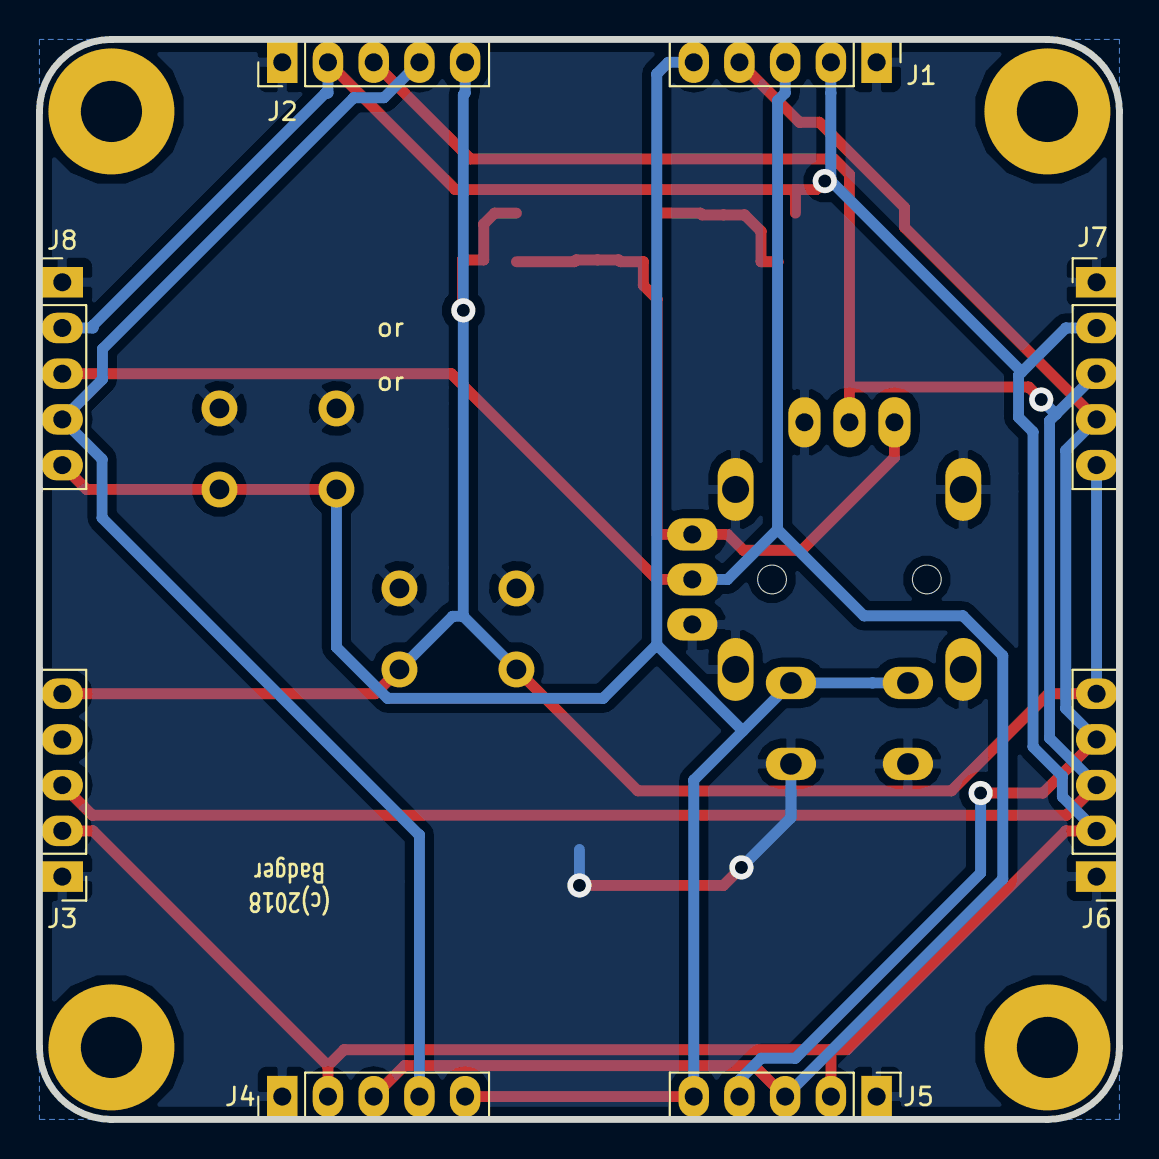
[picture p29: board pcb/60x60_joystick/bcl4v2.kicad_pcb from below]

Board: 2 copper layers, 60.0 x 60.0 mm, 21 parts (8 on the bottom side), 10 nets.

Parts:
C1, C3: 4u7; C_0805_HandSoldering
C2: 100n; C_0805_HandSoldering
J1, J2, J3, J4, J5, J6, J7, J8: Conn_01x05; badger_Pin_Hdr_1x05_2.54mm_handsolder
J9, J10, J11, J12: Conn_01x01_Female; badger_mount_M3
Q1: IRLML6402; badger_SOT-23_handsolder
R1: RKJXV1224_Joystick; badger_RKJXV1224 Joystick
R14: 220k; R_0805_HandSoldering
SW1, SW2: SW_Push; SW_PUSH_6mm_h5mm
U1: DS9166A-23; badger_SOT-23_handsolder

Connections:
+3V3: C3.1, R1.1, R1.4, R14.1, U1.2
+5V: C1.1, Q1.2, U1.3
/AOUT0: J2.3, J3.3, J6.3, J7.3, R1.2
/AOUT1: J1.3, J4.3, J5.3, J8.3, R1.5
/BTN0: J1.5, J4.5, J5.5, J8.5, R1.7, R1.8, SW2.1
/BTN1: C2.2, J2.5, J3.5, J6.5, J7.5, R14.2, SW1.1
/I2C_SCL: J1.4, J5.4, J6.4, J7.4
/I2C_SDA: J2.4, J4.4, J8.4
GND: C1.2, C2.1, C3.2, J1.1, J2.1, J3.1, J4.1, J5.1, J6.1, J7.1, J8.1, Q1.1, R1.3, R1.6, R1.9, R1.10, R1.11, R1.12, R1.13, R1.14, SW1.2, SW2.2, U1.1
VCC: J1.2, J2.2, J3.2, J4.2, J5.2, J6.2, J7.2, J8.2, Q1.3

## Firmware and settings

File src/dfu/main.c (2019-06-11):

#include <libopencm3/stm32/rcc.h>
#include <libopencm3/stm32/gpio.h>
#include <libopencm3/cm3/systick.h>
#include <libopencm3/cm3/nvic.h>
#include <libopencm3/stm32/flash.h>
#include <libopencm3/stm32/syscfg.h>
#include <libopencm3/stm32/memorymap.h>
#include <stdint.h>
#include <stddef.h>
#include <string.h>
#include "usart_tx.h"
#include "usb.h"
#include "main.h"
#include "disp.h"
#include "i2c.h"
#include "hw_defs.h"
#include <libopencm3/stm32/crc.h>
#include <stdlib.h>

#define DFU_DEBUG


volatile uint32_t tick_count;
static uint32_t serviced_tick;
int page_number;
uint8_t page_data[PAGE_SIZE] __attribute__ ((aligned (4)));
static bool usb_enabled;
static bool i2c_enabled;
static int i2c_crossover;
bool dfu_activated;
enum mode main_mode = MODE_STANDALONE;
static bool flashing;
bool ready_to_download;
static uint32_t next_page_time;
static int current_i2c_packet = -1;
static bool page_broadcasted;
static bool flash_done;
static bool page_erased;


struct vectors_header {
	uint32_t stack;
	uint32_t reset;
};

void sys_tick_handler(void)
{
	tick_count++;
}

void panic(void)
{
	while(1)
		;
}

static void ticker_init(void)
{
	/* set system ticker to fire every 1ms */
	systick_set_reload(rcc_ahb_frequency / 8 / 1000);
	systick_counter_enable();
	systick_interrupt_enable();

	/* clear counter so it starts right away */
	STK_CVR = 0;
}

static void ticker_teardown(void)
{
	systick_interrupt_disable();
	systick_counter_disable();
}

static void send_packet_i2c(void)
{
	tx_buf[0] = MSG_DATA;
	memcpy(tx_buf + 1, page_data + current_i2c_packet * PAGE_PACKET_SIZE, PAGE_PACKET_SIZE);
	i2c_tx_start(PAGE_PACKET_SIZE + 1);
}

static void send_flash_command(void)
{
	msg_flash* msg = (void*)tx_buf;
	crc_reset();
	msg->msgid = MSG_FLASH;
	msg->crc = crc_calculate_block((uint32_t*)page_data, PAGE_SIZE);
	msg->page = page_number;
	i2c_tx_start(sizeof(*msg));
}

static void flash_page(void) {
	uintptr_t page = FLASH_BASE + PAGE_SIZE * (FLASH_RESERVED_PAGES + page_number);
	if (memcmp((void*)page, page_data, PAGE_SIZE) == 0) {
		page_erased  = true;
		flash_done = true;
		return;
	}

	if (!page_erased) {
		page_erased = true;
		flash_unlock();
		flash_wait_for_last_operation();

		FLASH_CR |= FLASH_CR_PER;
		FLASH_AR = page;
		FLASH_CR |= FLASH_CR_STRT;
	} else if ((flash_get_status_flags() & FLASH_SR_BSY) == 0){
		FLASH_CR &= ~FLASH_CR_PER;
		for (size_t i = 0; i < PAGE_SIZE; i+= 4) {
			flash_program_word(page + i, *(uint32_t*)(page_data + i));
		}
		flash_lock();
		flash_done = true;
	}
}

void handle_page(void)
{
	ready_to_download = false;
	flash_done = false;
	page_broadcasted = false;
	page_erased = false;

	if (!flashing) {
		flashing = true;
		disp_show(icon_flash);
	}

	/* Kick of i2c resend */
	if (main_mode == MODE_MASTER) {
		current_i2c_packet = 0;
	}

	if (main_mode == MODE_STANDALONE || main_mode == MODE_SLAVE) {
		page_broadcasted = true;
	}
}

static void init_i2c_line_detect(void)
{
	gpio_set(I2C1_GPIO_PORT, I2C1_GPIO_SCL | I2C1_GPIO_SDA);
	gpio_set_output_options(I2C1_GPIO_PORT,
		GPIO_OTYPE_OD, GPIO_OSPEED_LOW, I2C1_GPIO_SCL | I2C1_GPIO_SDA);
	gpio_mode_setup(I2C1_GPIO_PORT,
		GPIO_MODE_OUTPUT, GPIO_PUPD_PULLUP, I2C1_GPIO_SCL | I2C1_GPIO_SDA);
	if (main_mode == MODE_MASTER)
		gpio_clear(I2C1_GPIO_PORT, I2C1_GPIO_SCL);
}

void continue_boot(void)
{
	if (main_mode == MODE_MASTER)
		i2c_send_release();

	uint32_t wait = tick_count + 5;
	while (wait < tick_count)
		;

	ticker_teardown();
	rcc_periph_reset_pulse(RST_USART1);
	rcc_periph_reset_pulse(RST_USART2);
	rcc_periph_reset_pulse(RST_USART3);
	rcc_periph_reset_pulse(RST_USART4);
	rcc_periph_reset_pulse(RST_USB);
	rcc_periph_reset_pulse(RST_I2C1);
	rcc_periph_reset_pulse(RST_I2C2);
	rcc_periph_reset_pulse(RST_GPIOA);
	rcc_periph_reset_pulse(RST_GPIOB);
	rcc_periph_reset_pulse(RST_GPIOC);
	rcc_periph_reset_pulse(RST_GPIOD);
	rcc_periph_reset_pulse(RST_GPIOE);

	rcc_periph_clock_disable(DISP_GPIOS_RCC);
	rcc_periph_clock_disable(I2C1_GPIO_RCC);
	rcc_periph_clock_disable(I2C2_GPIO_RCC);
	rcc_periph_clock_disable(RCC_USB);
	rcc_periph_clock_disable(RCC_I2C1);
	rcc_periph_clock_disable(RCC_I2C2);
	rcc_periph_clock_disable(RCC_USART1);
	rcc_periph_clock_disable(RCC_USART2);
	rcc_periph_clock_disable(RCC_USART3);
	rcc_periph_clock_disable(RCC_USART4);
	rcc_periph_clock_disable(LED_RCC);


	/* Copy the vectors to RAM, since we can map that at correct location */
	void *ram = (void*) 0x20000000;
	void *user_code = (void*) (FLASH_BASE + PAGE_SIZE * FLASH_RESERVED_PAGES);
	memcpy(ram, user_code, VECTOR_TABLE_SIZE);
	struct vectors_header *v = user_code;
	uint32_t stack = v->stack;
	uint32_t reset = v->reset;
	uint32_t syscfgr = SYSCFG_CFGR1;
	syscfgr &= ~SYSCFG_CFGR1_MEM_MODE;
	syscfgr |= SYSCFG_CFGR1_MEM_MODE_SRAM;
	SYSCFG_CFGR1 = syscfgr;

	/* jump & change stack */
	__asm__ __volatile__(
	    "mov sp, %[sp]\n"
	    "bx %[pc]"
	    :: [sp] "r" (stack), [pc] "r" (reset));
}
int main(void) {
	rcc_clock_setup_in_hsi_out_48mhz();
	rcc_periph_clock_enable(I2C1_GPIO_RCC);
	rcc_periph_clock_enable(I2C2_GPIO_RCC);
	rcc_periph_clock_enable(RCC_GPIOA);
	rcc_periph_clock_enable(RCC_GPIOB);
	rcc_periph_clock_enable(RCC_I2C1);
	rcc_periph_clock_enable(RCC_I2C2);
	rcc_periph_clock_enable(LED_RCC);
	/* turn on LED to indicate that we have power */
	gpio_mode_setup(LED_PORT, GPIO_MODE_OUTPUT, GPIO_PUPD_NONE, LED_PIN);
	gpio_set(LED_PORT, LED_PIN);
	ticker_init();
	disp_init();
	disp_show(icon_wait);
	usart_init();
	usb_init();
	usart_reset_neigbors();
	ready_to_download = false;
	page_broadcasted = true;
	flash_done = true;
	usb_enabled = true;
	i2c_enabled = false;

	/* Continue until time-out. If we are a slave or the user has started download,
	 * there is not time-out */
	while((tick_count < USB_WAIT_PHASE_END) || dfu_activated || (main_mode == MODE_SLAVE)) {
		if (serviced_tick == QUIET_PHASE_END) {
			init_i2c_line_detect();
			if (main_mode != MODE_MASTER) {
				rcc_periph_reset_pulse(RST_USB);
				usb_enabled = false;
			}
		}

		if (serviced_tick == LINE_DETECT_SAMPLE && main_mode != MODE_MASTER) {
			uint16_t lines = gpio_get(I2C1_GPIO_PORT, I2C1_GPIO_SCL | I2C1_GPIO_SDA);
			if (lines == I2C1_GPIO_SCL) {
				/* SDA driven low */
				i2c_crossover = 1;
				disp_show(icon_slave);
				main_mode = MODE_SLAVE;
			} else if (lines == I2C1_GPIO_SDA) {
				/* SCL driven low */
				i2c_crossover = 0;
				disp_show(icon_slave);
				main_mode = MODE_SLAVE;
			} else {
				/* don't know, assume everyone is dead */
				main_mode = MODE_STANDALONE;
			}
		}

		if (serviced_tick > LINE_DETECT_SAMPLE && main_mode == MODE_SLAVE && !i2c_enabled) {
			uint16_t lines = gpio_get(I2C1_GPIO_PORT, I2C1_GPIO_SCL | I2C1_GPIO_SDA);
			if (lines == (I2C1_GPIO_SCL | I2C1_GPIO_SDA)) {
				i2c_enabled = true;
				i2c_init(i2c_crossover, false);
			}
		}

		if (serviced_tick == LINE_DETECT_PHASE_END && main_mode == MODE_MASTER) {
			i2c_enabled = true;
			i2c_init(i2c_crossover, true);
		}

		if (serviced_tick == SLAVE_GIVE_UP && main_mode == MODE_SLAVE && !flashing) {
			continue_boot();
		}

		if (main_mode == MODE_MASTER && !page_broadcasted && i2c_enabled && !i2c_tx_running()) {
			if (current_i2c_packet == PAGE_SIZE/PAGE_PACKET_SIZE) {
				current_i2c_packet = -1;
				page_broadcasted = true;
				send_flash_command();
			} else if (current_i2c_packet >= 0){
				send_packet_i2c();
				current_i2c_packet++;
			}
		}

		if (page_broadcasted && !flash_done &&  (!i2c_enabled || !i2c_tx_running())) {
			next_page_time = tick_count + PAGE_FLASH_TIME;
			flash_page();
		}

		/* Allow flashing if we do not have any unfinished i2c packets, are in appropriate phase,
		 * and the next_page_time delat has elapsed */
		if (main_mode == MODE_MASTER
		    && next_page_time < tick_count
		    && current_i2c_packet == -1
		    && page_broadcasted
		    && flash_done
		    && serviced_tick > FLASHING_ALLOWED) {
			ready_to_download = true;
		}

		if (usb_enabled)
			usb_run();

		if (i2c_enabled) {
			if (!i2c_poll()) {
				disp_show(icon_flash_problem);
			}
		}

		if (serviced_tick < tick_count) {
			/* per-tick actions */
			serviced_tick++;
			disp_tick();

			/* Blink the LED */
			if (((serviced_tick / 500 % 2) == 0) == 0)
				gpio_set(LED_PORT, LED_PIN);
			else
				gpio_clear(LED_PORT, LED_PIN);
		}
	}

	continue_boot();
}

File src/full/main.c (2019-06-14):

#include <ch.h>
#include <hw/board.h>
#include <hw/led.h>
#include <hw/disp.h>
#include <hw/usart_buffered.h>
#include <hw/cdcacm.h>
#include <hw/led.h>
#include <hw/console.h>
#include <hw/i2c.h>
#include <hw/cell_id.h>
#include <util/topo.h>
#include <util/message_queue.h>
#include <util/mgmt_proto.h>
#include <util/icons.h>
#include <util/topo.h>
#include <util/initializers.h>
#include <applets/applet.h>
#include <assert.h>

#ifdef SIM
#include "sim/main.h"
#endif

static void main_task(void);

#ifdef SIM
int main(int argc, char* argv[])
{
	int ret = sim_main(argc, argv);
	if (ret != 0)
		return ret;
	board_init();
	chSysInit();
	main_task();
	return 0;
}
#else
int main(void)
{
	board_init();
	chSysInit();
	main_task();
	return 0;
}
#endif

extern const struct applet chooser_applet;

static void handle_bl_start(void)
{
#ifndef SIM
	scb_reset_system();
#endif
}

static void handle_mgmt_interrupt(void)
{
	// nothing yet
}

static void handle_change_applet(const buf_ptr *data)
{
	struct mgmt_change_applet msg;
	buf_ptr_read(data, 0, sizeof(msg), &msg);
	// console_printf("Change applet %d\n", msg.applet);
	applet_select_local(applet_get(msg.applet));
}

static THD_WORKING_AREA(mgmt_thread_area, 128);
static void mgmt_task(void *p)
{
	(void)p;
	while (1) {
		msg_header hdr;
		buf_ptr data;
		if (msg_rx_queue_get(mgmt_queue, &hdr, &data, TIME_INFINITE)) {
			switch (hdr.id) {
				case MGMT_BL_START:
					handle_bl_start();
					break;
				case MGMT_INTERRTUP:
					handle_mgmt_interrupt();
					break;
				case MGMT_CHANGE_APPLET:
					route_message(false, &hdr, &data);
					handle_change_applet(&data);
					break;
			}
			msg_rx_queue_ack(mgmt_queue);
		}
	}
}

static THD_WORKING_AREA(disp_test_thread_area, 128);
#define DISP_TEST_DLY TIME_MS2I(100)
static void disp_test_task(void *p)
{
	(void)p;

	disp_clean();
	int i;
	for (i=0 ;i<4;i++) {
		if (chThdShouldTerminateX())
			return;
		disp_set(i,i, 31);
		chThdSleep(DISP_TEST_DLY);
		if(i>0){
			disp_set(i-1,i-1, 0);
		}

		disp_set(i,7-i, 31);
		chThdSleep(DISP_TEST_DLY);
		if(i>0) {
			disp_set(i-1,7-i+1, 0);
		}

		disp_set(7-i,7-i, 31);
		chThdSleep(DISP_TEST_DLY);
		if (i>0) {
			disp_set(7-i+1,7-i+1, 0);
		}

		disp_set(7-i,i, 31);
		chThdSleep(DISP_TEST_DLY);
		if (i>0) {
			disp_set(7-i+1,i-1, 0);
		}
	}
}

static char hexdigit(uint8_t x) {
	return (x < 10 ? '0' + x : 'A' + x - 10);
}

static void print_banner(void)
{
	char cell_id_hex[CELL_ID_LEN*2 + 1];
	cell_id_hex[CELL_ID_LEN*2] = 0;
	const cell_id_t *id = get_cell_id();
	for(int i = 0; i < CELL_ID_LEN; i++) {
		cell_id_hex[i*2] = hexdigit(id->bytes[i] >> 4);
		cell_id_hex[i*2 + 1] = hexdigit(id->bytes[i] & 0xF);
	}
	console_printf("\nWelcome, this is DotMatrix board ID %s\n", cell_id_hex);
	console_printf("Assigned cell id: %d, master=%s\n",
		topo_my_id,
		topo_is_master ? "true": "false");
}

static void main_task(void)
{
	disp_init();
	led_on();

	run_all_initializers();
	thread_t *thr = chThdCreateStatic(mgmt_thread_area, sizeof(mgmt_thread_area), NORMALPRIO + 2, mgmt_task, NULL);
	thr->name = "mgmt";
	display_test = chThdCreateStatic(disp_test_thread_area, sizeof(disp_test_thread_area), NORMALPRIO, disp_test_task, NULL);
	display_test->name = "disp";

	topo_run();
	/* I2C needs the topology */
	i2c_init();
	chThdWait(display_test);
	print_banner();

	const struct applet* autostart = applet_autostart();
	if (autostart == NULL)
		applet_select_local(&chooser_applet);
	else
		applet_select_local(autostart);

	while (1) {
		if (topo_is_master) {
			/* Give others some time to start the applet */
			/* TODO: add some "barrier" mechanism for these instances */
#ifdef SIM
	chThdSleep(TIME_MS2I(300));
#else
	chThdSleep(TIME_MS2I(100));
#endif
		}
		applet_should_end = false;
		applet_current()->run();
		if (!applet_should_end) {
			chSysHalt("Applet ended unexpectedly");
		}
	}
}

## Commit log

2018-10-25 - add first prototype version of PCB
    [bcl4v2.brd, bcl4v2.dsn, bcl4v2.sch]
2018-10-28 - draft of 60x60mm version
    [bcl4v2.brd, bcl4v2.dsn, bcl4v2.kicad_pcb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]
2018-10-28 - brainstorming what can be connected to headers
    [60x60_mono_header_pins.ods]
2018-10-28 - make the headers better solderable
    [bcl4v2.kicad_pcb, bcl4v2.sch]
2018-10-29 - split schematics to more pages
    [Interfaces.sch, LED_matrix.sch, bcl4v2.sch]
2018-11-01 - add pins to the sheets, add reset/boot circuit
    [Interfaces.sch, LED_matrix.sch, bcl4v2.kicad_pcb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]
2018-11-01 - fix USB lines
    [Interfaces.sch, LED_matrix.sch, bcl4v2.kicad_pcb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]
2018-11-03 - replaced protection LEDs with mosfet
    [Interfaces.sch, LED_matrix.sch, _saved_bcl4v2.sch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]
2018-11-03 - pcb (hopefully) ready for first routing attempt
    [bcl4v2.kicad_pcb]
2018-11-03 - little bit more componnent shifting to ease soldering
    [bcl4v2.kicad_pcb]
2018-11-03 - fix unroutable corner
    [bcl4v2.kicad_pcb]
2018-11-03 -add missing LCD component footprint
    [bcl4v2.kicad_pcb]
2018-11-03 - don't commit kicad backup files
2018-11-03 - fix some footprints to reduce ERC errors
    [Interfaces.sch, LED_matrix.sch, _saved_bcl4v2.sch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]
2018-11-03 - add a simple joystick module
    [bcl4v2.brd, bcl4v2.dsn, bcl4v2.kicad_pcb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]
2018-11-03 - no need for edge cut for USB here
    [bcl4v2.kicad_pcb]
2018-11-03 - just before importing routed pcb from freeroute
    [bcl4v2.dsn]
2018-11-03 - imported freeroute output
    [bcl4v2.kicad_pcb]
2018-11-03 - routed pcb, filled zones
    [bcl4v2.kicad_pcb]
2018-11-03 - fix silkscreen
    [bcl4v2.kicad_pcb]
2018-11-03 - yet another silkscreen fine tuning
    [bcl4v2.kicad_pcb]
2018-11-12 - add note about mounting hole spacing
2018-11-13 38x38mm matrix with DMA
    initial version, almost completely routed, i2c interface missing
    [bcl4v3.kicad_pcb, bcl4v3.sch]
2018-11-13 Add LED matrix symbol/footprint
2018-11-13 Board update
    fully routed PCB
    indicator LED added
    [bcl4v3.kicad_pcb, bcl4v3.sch]
2018-11-16 PCB and schematics updates
    - exchange STM32F070 with STM32F072 (USB w/o HSE)
    - remove xtal and related components
    - add boot mode jumper pads (NO)
    - connect USB_VBUS with VCC via jumper (NC)
    - smaller clearance for pad to solder mask
    - add local library directory for externally imported
    symbols, footprints and 3D models
    PCB outline
    add small cut-out for USB receptacle
    [bcl4v3.kicad_pcb, bcl4v3.sch]
2018-11-18 PCB updates for panelization
    - place USB receptacle and edge cut-out smack center of the right board edge
    - rounded cut-out (.4mm radius) to allow routing it out using a single
    0.8mm wide slot.
    [bcl4v3.kicad_pcb]
2018-11-19 - quick sketch of bicolor 60x60 pcb
    [Interfaces-2018-11-18-15-53-39.sch, Interfaces.sch, LED_matrix-2018-11-18-15-53-39.sch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]
2018-11-25 - add missing header, more cleanup
    [main.c]
2018-11-25 - switch to next hw revision
2018-11-27 PCB and schematics cleanup
    resize PCB to exactly 38x38mm, center the LED matrix
    add OSHW logo to silk screen, add copyright information
    [bcl4v3.kicad_pcb, bcl4v3.sch]
2018-11-28 Fix reverse voltage protection, cleanups
    - power from USB doesn't need to go through protection FET
    - power to 3.3V LDO _must_ got through protection FET
    - add OSHW logo also to schematics so that it doesn't vanish if you
    sync PCB and schematics
    - modify copyright info a bit
    [bcl4v3.kicad_pcb, bcl4v3.sch]
2018-11-30 Add test points, small routing changes
    - add test points for SPI bus
    - add net classes for VCC and LED networks
    - small routing changes
    [bcl4v3.kicad_pcb, bcl4v3.sch]
2019-01-15 - copy led driving schematic, from 38x38_dma, change switches
    [Interfaces.sch, LED_matrix.sch, bcl4v2.brd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]
2019-01-18 - just before autoroute
    [bcl4v2.dsn, bcl4v2.kicad_pcb]
2019-02-12 - add 60x60_dma version
    [Interfaces.sch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]
2019-03-05 - add some testpoints
    [Interfaces.sch, LED_matrix.sch, bcl4v2.sch]
2019-03-24 - fix display connections, add testpoints
    [Interfaces.sch, LED_matrix.sch, bcl4v2.kicad_pcb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]
2019-03-26 - add LSE crystal (needs to fix routing and zones)
    [bcl4v2.kicad_pcb, bcl4v2.sch]
2019-03-31 - larger USB pads, larger switch cuts, silk fixes
    [bcl4v2.kicad_pcb]
2019-03-31 -add simple solder testing board
    [bcl4v2.brd, bcl4v2.dsn, bcl4v2.kicad_pcb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]
2019-03-31 - panelize in design
    [bcl4v2.kicad_pcb]
2019-04-16 - partially filled BOM
    [bcl4v2_bom.csv]
2019-04-16 - add more details in BOM
    [bcl4v2_bom.csv]
2019-04-16 - add assembly manual skeleton
2019-04-20 - merge in dma branch and lot of fixups - merge in dma branch - some renaming in the header file, to make it more consistent - workaround for wrong column order in rev 0.4, need to be reverted for ne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
    [disp.c]
2019-04-21 - move the debug LED handling to separate file
2019-04-21 - add simple (useless for now) button example
2019-04-28 - add OSHV logo, move LED a bit
    [LED_matrix.sch, bcl4v2.kicad_pcb, bcl4v2.sch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]
2019-04-28 -refill zones
    [bcl4v2.kicad_pcb]
2019-04-28 - do the fabrication output
    [bcl4v2-B.Mask.gbr, bcl4v2-B.SilkS.gbr, bcl4v2-Back.gbr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]
2019-04-28 - add display support and joints
    [disp_support.scad, disp_support.stl, joint_2x2_10mm.stl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]
2019-05-27 - add bards joint scad file
    [joint.scad]
2019-05-27 -add cut for LED on rev 0.5
    [joint.scad, joint_cross_1_5m_cut_for_v05.stl]
2019-05-27 Initial version of the simulator, can show the display and LED status.
2019-05-31 Restore the ability to run on a real device.
2019-06-02 Support uart and gpio in simulator.
    The UART was also reworked to support framing for some future
    applications.
    [life.c, main.c, main.py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]
2019-06-03 Make it actually work on a device.
2019-06-03 Add button support on real device.
2019-06-03 Add basic Distributed DFU support.
    Currently it is not distributed, but it is DFU.
2019-06-04 Use correct header memory.h -> string.h
    [buttons_hw.c, disp.c, main.c]
2019-06-05 Working sim & device under ChibiOS.
    Still does not take advantage of the OS.
2019-06-08 Ported full demo fully to ChibiOS.
    The most prominent feature is the UART queues. So fart buttons are not
    supported yet and common_gpio is a hack (which will hopefully be
    replaced by i2c).
    [board.c, chconf_common.h, chooser_applet.c]
2019-06-08 Fix some usart problems on target and increase stack.
    _snprintf is a memory hog.
    [board.c, chconf_common.h, main.c]
2019-06-08 Initializer rework & button support.
    We do not need the full worker infrastructure, we can fire of tasks or
    register virtual timers instead of polling.
    [board.c, buttons.c, buttons_hw.c]
2019-06-08 Let each cell know its position and orientation.
    This is important for display autorotation and i2c (comming next).
2019-06-08 - clense the schematics
    [Interfaces.sch, LED_matrix.sch, bcl4v2.sch]
2019-06-08 - allow setting path to the arm-none-eabi in settings.mk
2019-06-08 - LED on to indicate that the board is powered
2019-06-08 - replace smile with disp driver test
    [main.c]
2019-06-09 I2C support. Life and applet chooser ported to i2c.
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2019-06-09 Add i2c distributed boot support to DDFU.
    Can not yet flash, but master/slave relationship is established during boot
    and master releases this slave. Actual flashing is comming.
2019-06-09 Fix chooser applet timeout.
    [chooser_applet.c]
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2019-06-09 Fix dfu page 0 not being flashed on slaves.
    [chooser_applet.c, i2c.c]
2019-06-09 Simplify & improve HW cleanup by doing peripheral reset.
    [i2c.c, main.c]
2019-06-10 Fix GameOfLife queing. Should also fix _ack in the future to prevent this mistake.
    [life.c]
2019-06-10 Add rebuild all, fix some warnings.
    [miniblink.c]
2019-06-10 Harden DFU i2c.
    1) Make sure the slave times out if it receives no instructions.
    2) The master times out on sending the release packet if it can not be
    sent.
2019-06-10 Small i2c TX rewrite.
    Main problem was the reversed sense of binary semaphore (also fixed in
    buttons) and not enabled STOPIE.
    [buttons.c, i2c.c]
2019-06-10 Fixup the DFU state machine & page timeouts.
    Time-stretching also disabled.
    [i2c.c, main.c]
2019-06-10 Remove the debug on reject and fix some OOB in i2c rx.
    [i2c.c]
2019-06-10 Add i2c recovery features.
    There was also nasty bug with calling console_printf in ISR. And
    console_printf uses exuberant amount of stack.
    [i2c.c, main.c]
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2019-06-11 Push the programming to the background.
    Remove extra file commited by mistake.
    [main.c]
2019-06-11 Switch the wait_for_dfu script to polling.
    The wait for device phase can also be skipped.
2019-06-11 Fix some communication errors on larger setups.
    Bootloader had wrong even/odd i2c detection and similar problem was in
    the even/odd i2c based on topology in full demo (caused by the ABS
    function).
    [main.c]
2019-06-11 Implement custom __asert_fail. Avoids last dependency on newlib printf.
    [board.c]
2019-06-12 Fixup paths after rename.
    [board.c, buttons_hw.c, chconf_common.h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]
2019-06-12 Reformat & verify the old demos with bootloader.
    Robert reported they were not working. Miniblink was indeed broken.
    [miniblink.c]
2019-06-12 Fix misleading file name.
    [bitbang.c]
2019-06-14 - update schematics export, few words about hw
2019-06-14 Remove worldclock - not relevant for the soldering workshop.
2019-06-26 - add pockets for magnets
    [disp_support.scad, disp_support_w_magnet.stl]
2019-07-08 -- pogo pin connector attempt
    [bcl4v2-B.Mask.gbr, bcl4v2-B.SilkS.gbr, bcl4v2-Back.gbr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]
2019-07-30 - make larger holes for pogo pins
    [bcl4v2-B.Mask.gbr, bcl4v2-B.SilkS.gbr, bcl4v2-Back.gbr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]

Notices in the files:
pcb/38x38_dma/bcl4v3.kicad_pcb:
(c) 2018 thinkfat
